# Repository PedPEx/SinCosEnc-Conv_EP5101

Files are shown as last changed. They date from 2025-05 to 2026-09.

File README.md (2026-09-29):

# EP5101 SinCos $11µA_{PP}$ and $1V_{PP}$ encoder/glass scale to TTL (RS422 compliance) converter (ARCHIVED)

This repo is no longer maintained. There is no reason to interface $11µA_{PP}$ sensors with the help of this PCB and an EtherCAT-based incremental encoder input module - like an EL5101 or an EP5101. Due to the cost of one assembled converter PCB (~30€ total), it is a competitive alternative to the original iC-Haus EVAL board of the [iC-NV](https://www.ichaus.de/product/ic-nv/) and the Heidenhain EXEs, if used with other RS422 or TTL encoder inputs.

If you are planning on using EtherCAT as your system bus, use the [documented process here on how to modify an EL5021 terminal](https://github.com/PedPEx/EL5021_multi-signal-mod) instead (which internally uses an iC-Haus IC similar to this project).

In my [bachelor's thesis](https://pedpex.github.io/Maho400E-LinuxCNC/docs/bachelors_thesis.pdf) I updated the old 0.9.6/0.9.7 version of the PCB a little, so that it better tolerates EMI conditions. As I was not very happy with the improvements in v0.9.8, it was never officially pushed. After further inspection, starting from scratch would be the better decision in order to get better EMI ratings. Additionally, the shielding of the EP5101-0011 is floating, which is also not the desired state. Since the alternative is far cheaper, a 4-layer redesign is not worthwhile, and as the new board is no longer used, this project will no longer be maintained and will therefore be archived.

PCB version v0.9.6 was fully working and successfully tested. Version v0.9.8 was never produced nor tested.
This board is provided as is - unfinished and untested. Productive use is explicitly not recommended! Further rework is required. No support is offered for it. The project will be left as is.

---

<details>
  <summary>Old README content</summary>
  
# EP5101 SinCos $11µA_{PP}$ and $1V_{PP}$ encoder/glass scale to TTL (RS422 compliance) converter (WIP!)
This interface board is designed to convert a encoder signal with $11µA_{PP}$ (peak-peak) or $1V_{PP}$ signal to TTL with a [iC-Haus iC-NV](https://www.ichaus.de/product/ic-nv/) be used with a [Beckhoff EP5101](https://www.beckhoff.com/de-de/produkte/i-o/ethercat-box/epxxxx-industriegehaeuse/ep5xxx-winkel-wegmessung/ep5101-0011.html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) for example in LinuxCNC.

Assembly concept (with old potentiometer and RJ45 jack):

Single encoder input             |  Three encoder inputs with terminal blocks
:-------------------------:|:-------------------------:
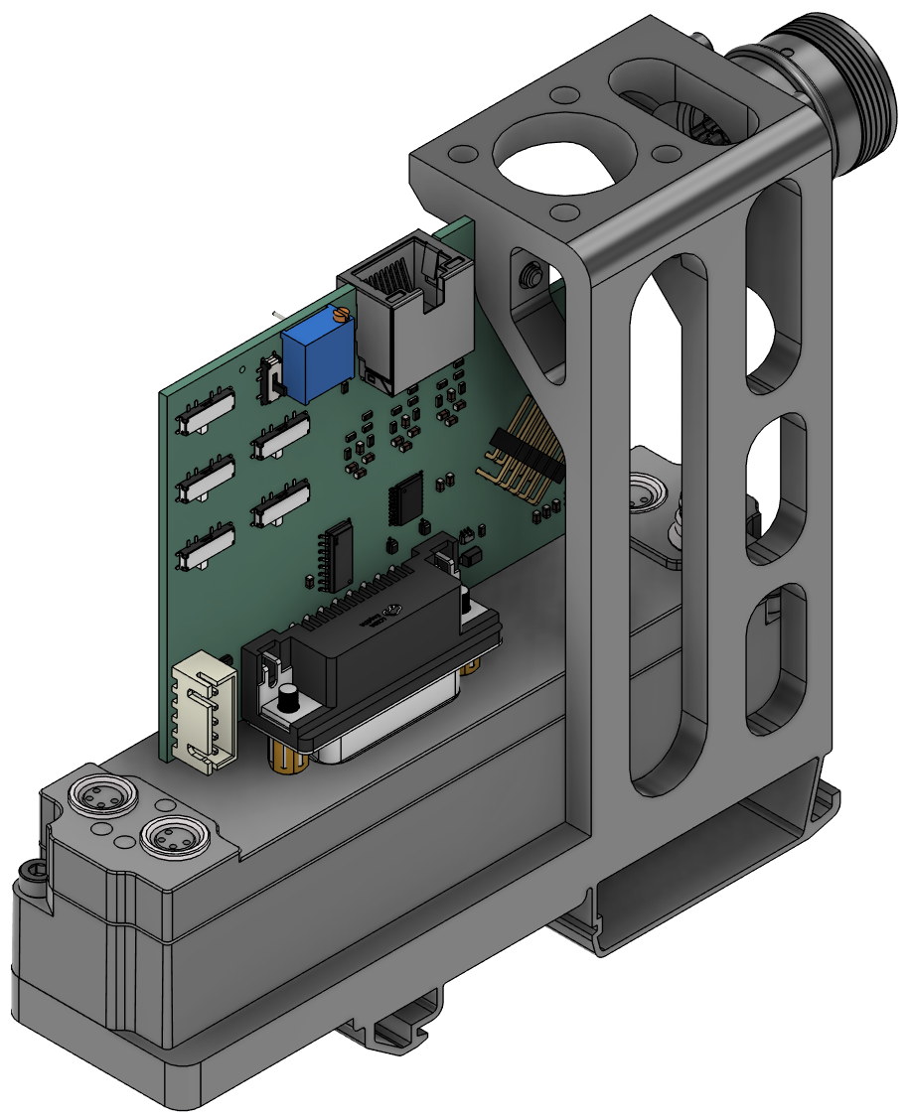
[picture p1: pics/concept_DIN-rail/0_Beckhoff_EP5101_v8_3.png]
assembly concept Concept assembly
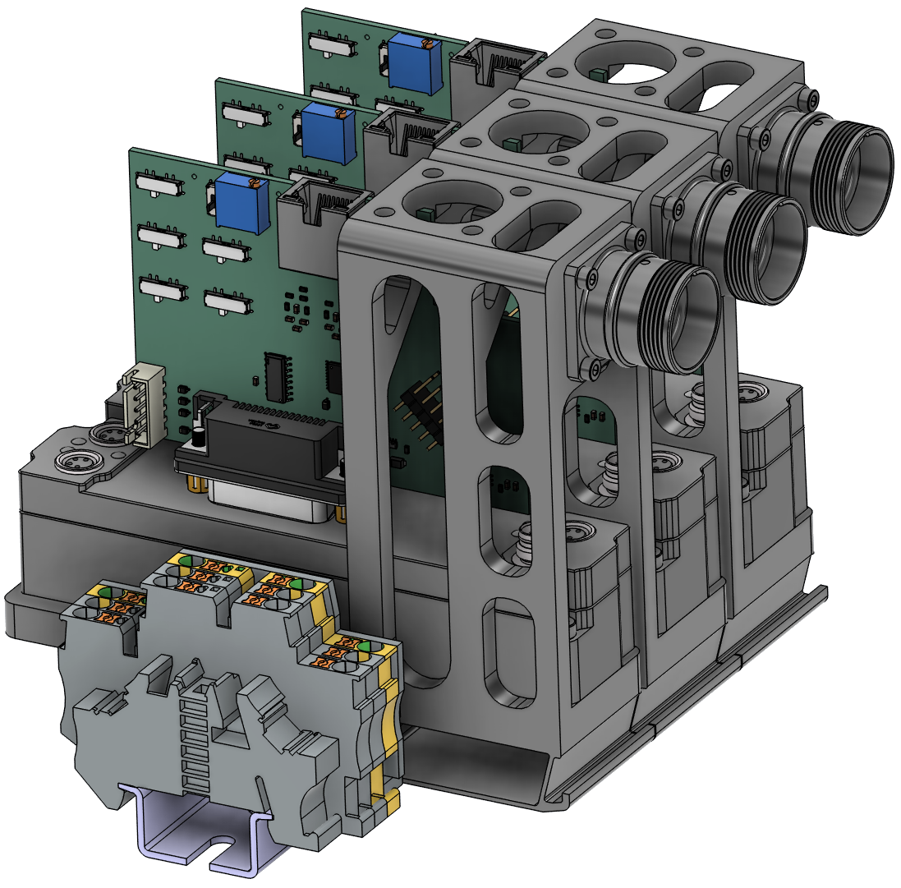
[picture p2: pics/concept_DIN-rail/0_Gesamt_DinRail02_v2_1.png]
assembly concept Concept assembly
  |  

PCB:\
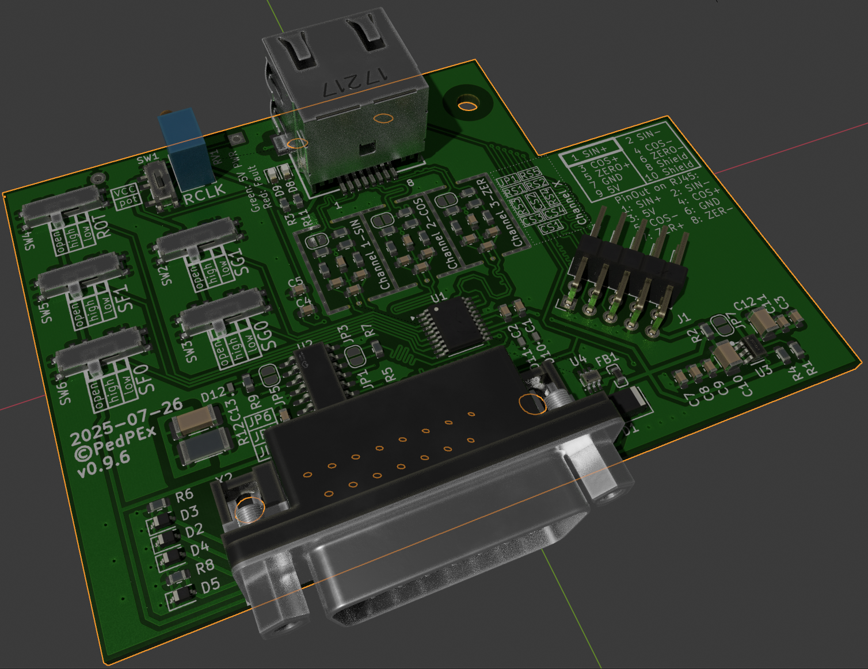
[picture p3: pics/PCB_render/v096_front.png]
PCB render v0.9.6 front

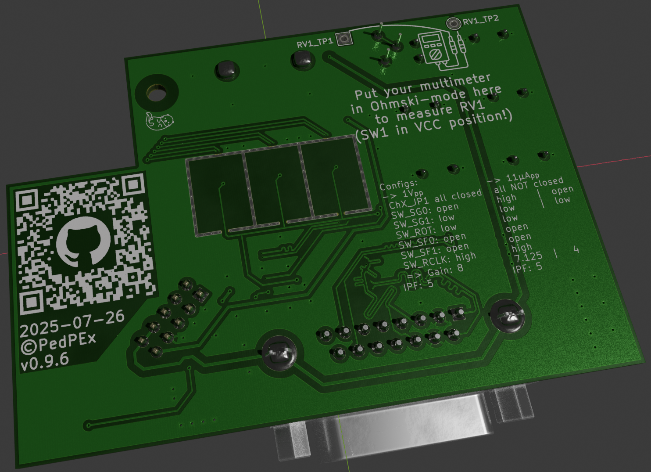
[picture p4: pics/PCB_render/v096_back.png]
PCB render v0.9.6 back


## ToDo
- ✅ finished prototype PCB (v0.9.6)
- ✅ working conversion
- ✅ tested intensively with [LS403](docs/Heidenhain-LS-403-LS-403C.pdf) and [EP5101](https://www.beckhoff.com/de-de/produkte/i-o/ethercat-box/epxxxx-industriegehaeuse/ep5xxx-winkel-wegmessung/ep5101-0011.html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)

## Powering, connectors and signals
The board needs no seperate supply voltage and is fully powered by the 5V supply of the EP5101. The green led indicates a working 5V sensor rail. Supported input signals are $11µA_{PP}$ (standard) and $1V_{PP}$. By default, the output is a differential RS422 TTL-encoder signal. In that case, component ```U2``` ([AM26LS31](https://www.ti.com/product/de-de/AM26LS31) - Differential Line Driver) is populated on the PCB. By removing ```U2``` and either manualy shorting ```JP1 - JP6``` or populating ```R5 - R10``` with $0 \Omega$ resistors (manual adjustment of BOM is required). 

Because the [Beckhoff EL5101](https://www.beckhoff.com/de-de/produkte/i-o/ethercat-klemmen/el5xxx-winkel-wegmessung/el5101.html) is way more common than the EP5101, a 3D printable holder is in the works and will also be added to the repo, as soon as it has reached a usable state. 

There could also be a master-PCB, which would be used in standalone use or with a Mesa FPGA board. This master-PCB would need a 24V to 5V regulator and three DSUB15 female connectors in order to connect to the interpolator PCBs and three connectors (RJ45 eventually?) to connect the TTL signals to the Mesa encoder inputs. A integrated DIN rail mount would make mounting easy. In case there is interest in such a board, feel free to open a issue and i will design one. 

## Mounting adaptor
There is a DIN-rail mounting adaptor avaliable, which is used to mount a M23 male connector and a EP5101 onto a 35 mm standard rail. You can find the [files to 3D print](https://than.gs/m/1345234) it yourself over on my Thangs-account.

## Config switches
Pretty much everything of the [iC-NV](https://www.ichaus.de/product/ic-nv/) is configurable through config switches and a potentiometer ($50 k\Omega$). The two most common configs are printed on the backside of the PCB

## Terminal blocks, connectors and pinouts
The shielded DSUB15 port has the following pinout:

| pin DSUB15 | usage/signal |
| :---  | :--- |
| 1 | DifSig_A+ / TTL_A |
| 2 | GND |
| 3 | DifSig_B+ / TTL_B |
| 4 | 5V VCC |
| 5 | n.c. |
| 6 | n.c. |
| 7 | DifSig_C- / TTL_GND  |
| 8 | n.c.  |
| 9 | DifSig_A- / TTL_GND  |
| 10 | GND  |
| 11 | DifSig_B- / TTL_GND  |
| 12 | 5V VCC  |
| 13 | E̅R̅R̅O̅R̅ out |
| 14 | DifSig_C+ / TTL_B  |
| 15 | n.c.  |

The shielded RJ45 port has the following pinout:

| pin RJ45 | usage/signal |
| :---  | :--- |
| 1 | In_SIN+ |
| 2 | In_SIN- |
| 3 | +5 V |
| 4 | In_COS+ |
| 5 | In_COS- |
| 6 | GND |
| 7 | In_ZERO+  |
| 8 | In_ZERO-  |

The 8 pin male-header J2 has the following pinout (standard Heidenhain pinout):

```
                        odd pins  |  even pins
╔════╦════╗             ----------|------------
║  1 ║  2 ║════════      In_SIN+  |  In_SIN-
╠════╬════╣                       |
║  3 ║  4 ║════════      In_COS+  |  In_COS-
╠════╬════╣                       |
║  5 ║  6 ║════════     In_ZERO+  |  In_ZERO-
╠════╬════╣                       |
║  7 ║  8 ║════════          GND  |  Shield
╠════╬════╣                       |
║  9 ║ 10 ║════════          +5V  |  Shield
╚════╩════╝
```

*Note:*\
DO ONLY CONNECT ONE SENSOR INPUT! NEVER USE THE PINHEADER AND RJ45 SIMULTANEOUSLY!

## Analog Frontend / Signal Conditioning Stage
After reaching out to iC-Haus' support for some details about the needed analog frontend for $11 µA_{PP}$ sensors, i got some details on how to implement it. A really nice solution which works with $1 V_{PP}$ as well as $11 µA_{PP}$ signals was documented in the [iC-NQC datasheet (page 28)](docs/iC-NQC_datasheet_E2en.pdf). This exact signal conditioning stage was implemented for all three stages. By shorting each ```CHx_JP1``` you can connect the $120 \Omega$ termination resistor to the input side of the input stage and by that set the device to its $1 V_{PP}$ operating mode.

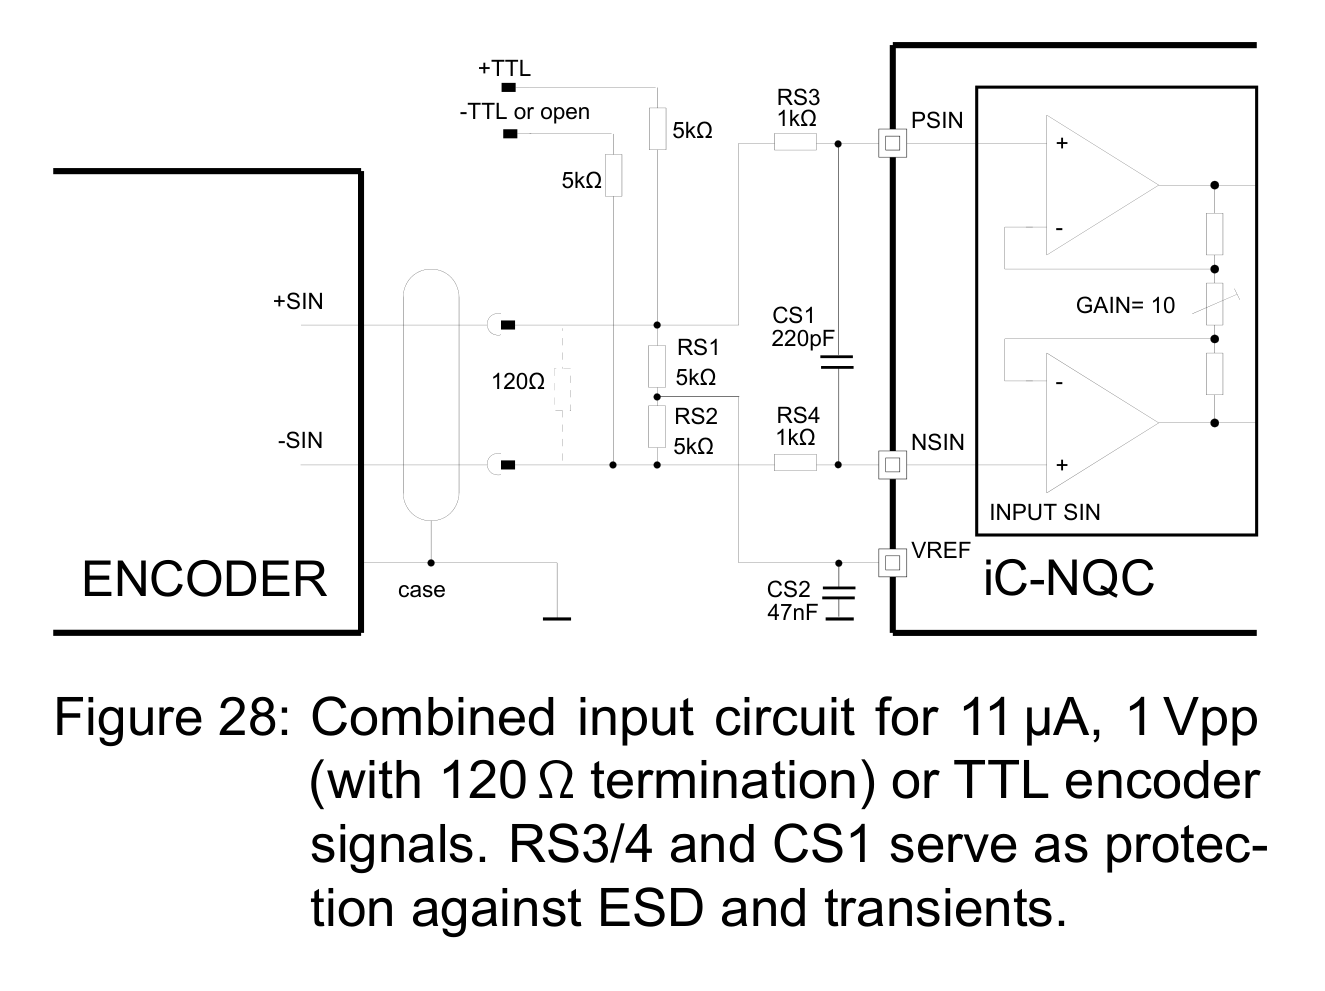
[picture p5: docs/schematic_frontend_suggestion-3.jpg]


## Usage/Software
This interface board is meant to be used in combination with the [Beckhoff EP5101 module](hhttps://www.beckhoff.com/de-de/produkte/i-o/ethercat-box/epxxxx-industriegehaeuse/ep5xxx-winkel-wegmessung/ep5101-0011.html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). The EP5101 is then used by the [LinuxCNC software](https://linuxcnc.org/) to read e.g. Heidenhain LS403 glass scales on a Maho MH400E.

A adaptor/mounting kit is in the works, that this project can also be used with [Beckhoffs EL5101](https://www.beckhoff.com/de-de/produkte/i-o/ethercat-klemmen/el5xxx-winkel-wegmessung/el5101.html) encoder inputs.

Also keep in mind that you need a sufficiently sized counter. For most retrofits a 16 bit wide counter will not cut it. 
Quick example:
```math 
n_{min} = \log_2 \left(\frac{range\_of\_motion}{axis\_resolution}\right) = \log_2 \left(\frac{400 mm}{1 \mu m}\right) = 18.61 bit \approx \textbf{19 bit > 16 bit}
```
In addition to the resolution you you also need to check the cutoff frequency (maximum input frequency) of the encoder input. The ```EP5101-0011``` for example is limited to $1.0 MHz$ (that's really high, especally in fourfold evaluation mode). For a resolution of $1 µm$ the maximum axis speed is:
```math
v_{max\_EC-Input} = \frac{resolution\_of\_sensor}{interpolation\_factor \cdot quadratur\_encoder\_input} \cdot cutoff\_frequency = {overall\_resolution \cdot cutoff\_frequency} = \frac{20µm}{5 \cdot 4} \cdot 1.0 MHz = 1µm \cdot 1.0 MHz = 1.0 \frac{m}{s}
```
The same calculation needs to be done with the input side of the IC ```iC-NV```. The cutoff frequency depends on the used gain. For a $gain = 4$ the manual states a $fin_{MAX}=200 kHz$ (for RCLK = VCC).
```math
v_{max\_IC-Input} = resolution\_of\_sensor \cdot cutoff\_frequency_{IC} = 20µm \cdot 200 kHz = 4.0 \frac{m}{s}
```
The lower value of the two calculated velocities, $v_{max\_{EC-Input}} = 1.0 \frac{m}{s}$ and $v_{max\_IC-Input} = 4.0 \frac{m}{s}$, is $1.0 \frac{m}{s}$. This represents the maximum permissible speed for the corresponding axis and must not be exceeded!

## Documentation
All docs can be found in the [docs folder](docs/).

## Online Preview / BOM
[Detailed schematics preview](https://kicanvas.org/?github=https%3A%2F%2Fgithub.com%2FPedPEx%2FSinCosEnc-Conv_EP5101) (KiCanvas)

[Online BOM](https://htmlpreview.github.io/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)

[PDF schematics (v0.9.6)](https://github.com/PedPEx/SinCosEnc-Conv_EP5101/blob/master/SinCosEnc-Converter_EP5101-0011_schematic_v0.9.6.pdf)

## *Note*
The pictures were rendered with the help of Blender and the [pcb2blender](https://github.com/30350n/pcb2blender) plugin and the HTML BOM was created with [InteractiveHtmlBom](https://github.com/openscopeproject/InteractiveHtmlBom).

</details>

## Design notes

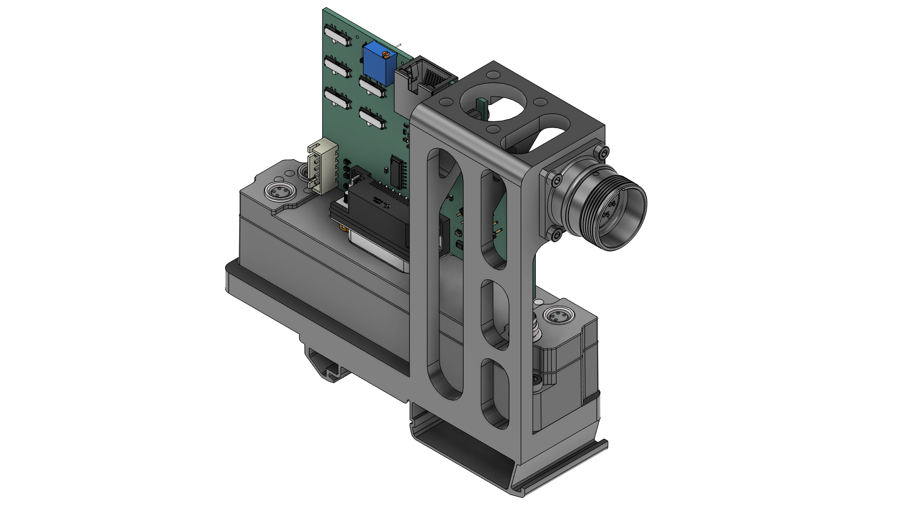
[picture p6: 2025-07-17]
pics/concept_DIN-rail/0_Beckhoff_EP5101_v8_1.png

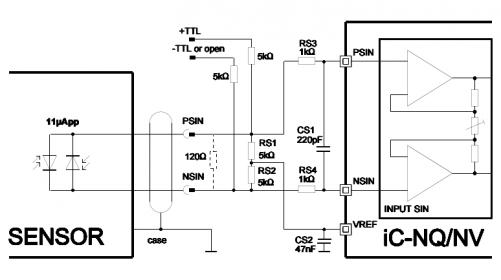
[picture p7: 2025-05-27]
docs/schematic_frontend_suggestion-1.jpg

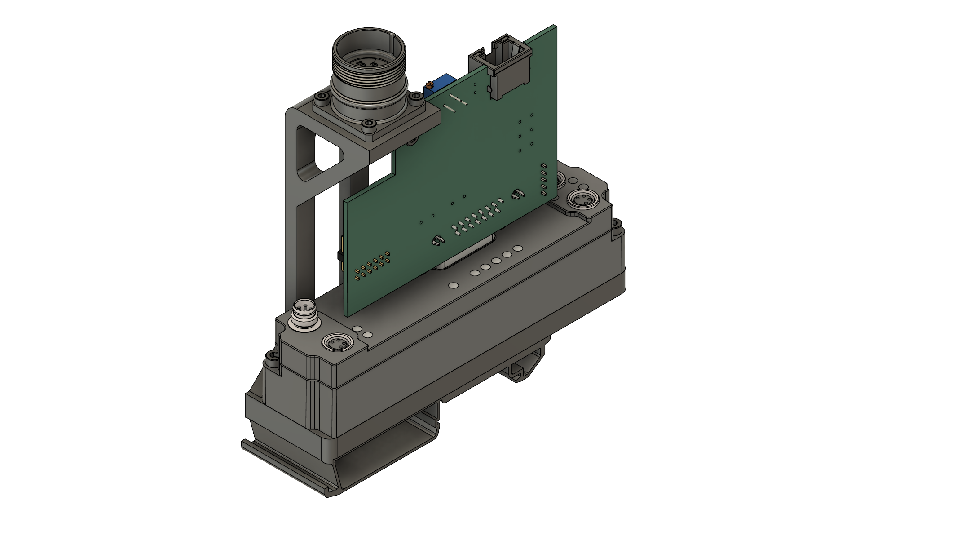
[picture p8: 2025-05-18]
pics/concept_DIN-rail/0_Beckhoff_EP5101_v4_1.png

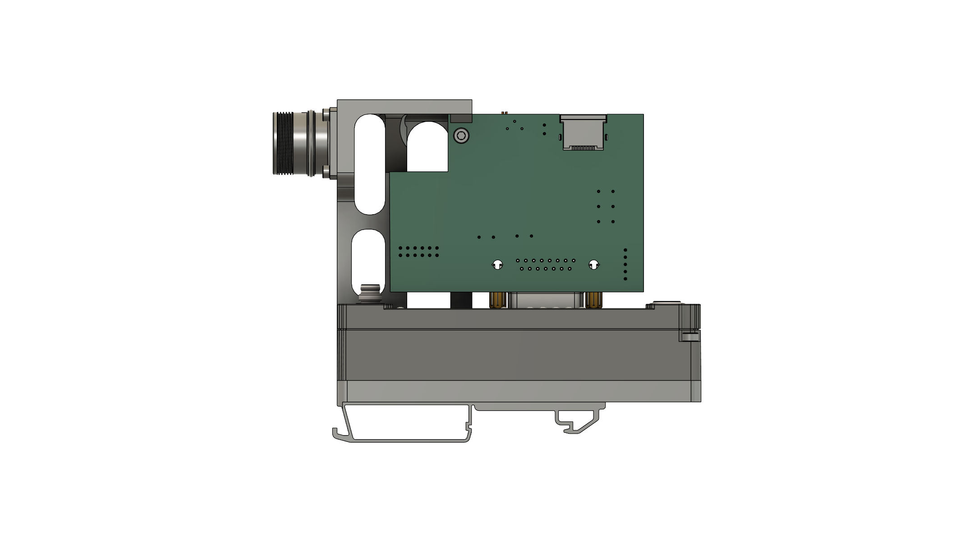
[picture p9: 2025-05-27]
pics/concept_DIN-rail/0_Beckhoff_EP5101_v5_4.png

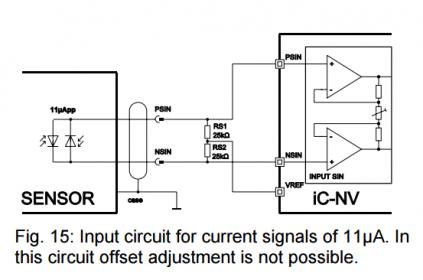
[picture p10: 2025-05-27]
docs/schematic_frontend_suggestion-2.jpg

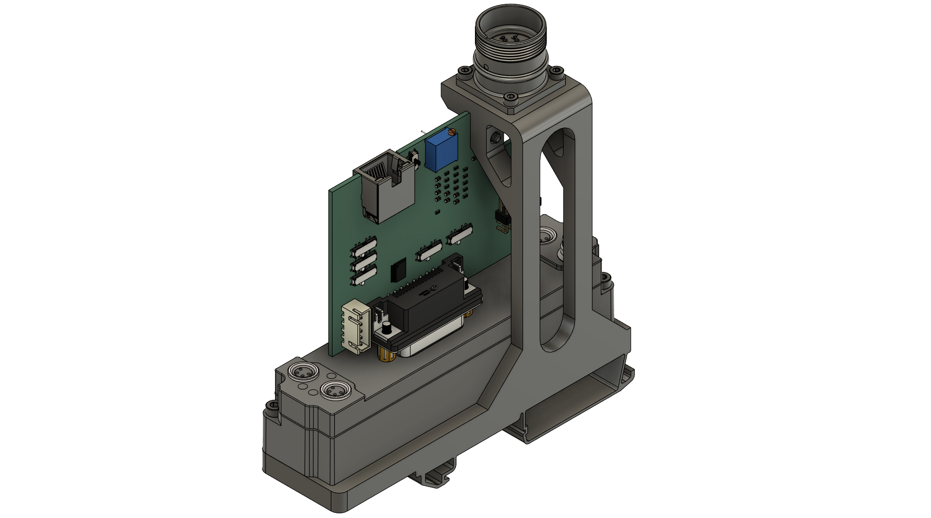
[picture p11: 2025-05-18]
pics/concept_DIN-rail/0_Beckhoff_EP5101_v4_6.png

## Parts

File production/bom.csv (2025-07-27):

Designator | Footprint | Quantity | Value | LCSC Part #
C1, C2, C4, C5, C6, C7 | 0603 | 6 | 100n
C10, C12 | 1206 | 2 | 47u | C94034
C11 | 0603 | 1 | 0.1u
C13 | 1808 | 1 | 4n7 | C161101
C3 | 0603 | 1 | 4u7 | C1705
C8 | 0603 | 1 | 1u
C9 | 0603 | 1 | 10u
Ch1_CS1, Ch2_CS1, Ch3_CS1 | 0603 | 3 | 220p
Ch1_CS2, Ch2_CS2, Ch3_CS2 | 0603 | 3 | 47n
Ch1_CS3, Ch1_CS4, Ch2_CS3, Ch2_CS4, Ch3_CS3, Ch3_CS4 | 0603 | 6 | 470p
Ch1_RS1, Ch1_RS2, Ch2_RS1, Ch2_RS2, Ch3_RS1, Ch3_RS2 | 0603 | 6 | 50k | C861451
Ch1_RS3, Ch1_RS4, Ch2_RS3, Ch2_RS4, Ch3_RS3, Ch3_RS4 | 0603 | 6 | 1k
Ch1_RS5, Ch2_RS5, Ch3_RS5 | 0603 | 3 | 120
D1 | D_SMA | 1 | SMAJ5.0CA | C83324
D10, D11, D12 | Texas_DPY0002A_0.6x1mm_P0.65mm | 3 | ESD401DPYR | C1974752
D2, D3, D4, D5, D6, D7 | D_SOD-323 | 6 | SD15 | C207245
D8 | 0603 | 1 | LED RED | C2986060
D9 | 0603 | 1 | LED GREEN | C2986059
FB1 | L0603 | 1 | 100R@100MHz | C107332
J1 | PinHeader_2x05_P2.54mm_Horizontal | 1 | Conn_02x05_Top_Bottom | C492433
R1 | 0603 | 1 | 215k | C22954
R10, R2, R5, R6, R7, R8, R9 | 0603 | 7 | 0
R11, R3 | 0603 | 2 | 470
R12 | 2010 | 1 | 1M | C2779367
R4 | 0603 | 1 | 10k
RJ1 | RJ45-SMD_6339160-1 | 1 | 6339160-1 | C125076
RV1 | Potentiometer_Bourns_3266X_Horizontal | 1 | 50k | C780222
RV1_TP1 | TestPoint_THTPad_2.0x2.0mm_Drill1.0mm | 1 | TestPoint_RV1
RV1_TP2 | TestPoint_THTPad_D2.0mm_Drill1.0mm | 1 | TestPoint_RV1
SW1 | SW-SMD_XKB_SS-3292S-L2-W | 1 | SW_RCLK | C2884756
SW2 | SW-SMD_MSK13C02-BB | 1 | SW_SG1 | C5149819
SW3 | SW-SMD_MSK13C02-BB | 1 | SW_SG0 | C5149819
SW4 | SW-SMD_MSK13C02-BB | 1 | SW_ROT | C5149819
SW5 | SW-SMD_MSK13C02-BB | 1 | SW_SF1 | C5149819
SW6 | SW-SMD_MSK13C02-BB | 1 | SW_SF0 | C5149819
U1 | TSSOP-20_4.4x6.5mm_P0.65mm | 1 | iC-NV
U2 | SOIC-16_L9.9-W3.9-P1.27-LS6.0-BL | 1 | AM26LS31CDR | C6179
U3 | SOT-23-6_L2.9-W1.6-P0.95-LS2.8-BL | 1 | AP22652AW6-7 | C5329413
U4 | SC-70-6_L2.0-W1.3-P0.65-LS2.1-BL | 1 | LM66100DCKR | C2869734
X2 | DSUB-TH_D-SUB-DR-15PCG-AB | 1 | D-SUB-DR-15PCG-AB | C19077347

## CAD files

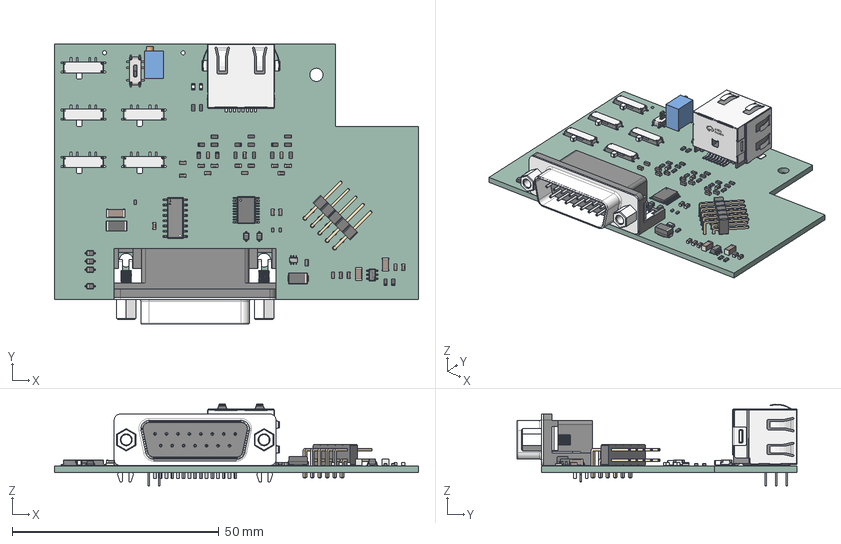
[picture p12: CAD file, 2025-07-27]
3D/SinCosEnc-Converter_EP5101-0011_v096.step
88.0 x 67.8 x 19.7 mm
R_2010_5025Metric
C_0603_1608Metric x 22
D_SMA
R_0603_1608Metric x 19
X1SON-2_L1.0-W0.6-H0.4-P0.65 x 3
SOT-23-6_L2.9-W1.6-H1.5-LS2.8-P0.95
SC-70-6_L2.0-W1.3-P0.65-LS2.1-BL
SOIC-16_L9.9-W3.9-H1.8-LS6.0-P1.27
SW-SMD_MSK13C02-BB x 5
C_1206_3216Metric x 2
Potentiometer_Bourns_3266X_Horizontal
LED_0603_1608Metric x 2
D_SOD_323 x 6
TSSOP_20_44x65mm_P065mm
SW-SMD_SS-3292S-L2-B
C_1808_4520Metric
PinHeader_2x05_P254mm_Horizontal
DSUB-TH_D-SUB-DR-15PCG-AB
L0603_L1.6-W0.8-H0.5_BEAD
RJ45-SMD_6339160-1
SinCosEnc-Converter_EP5101-0011_PCB

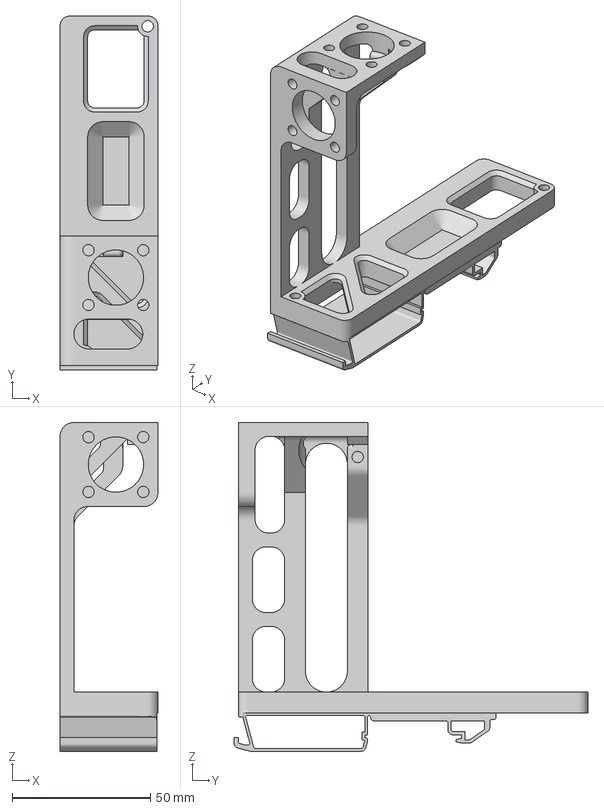
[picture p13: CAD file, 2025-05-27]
3D/EP5101-0011_DinRail_CON-downside_v4.3mf
35.4 x 128.0 x 119.0 mm

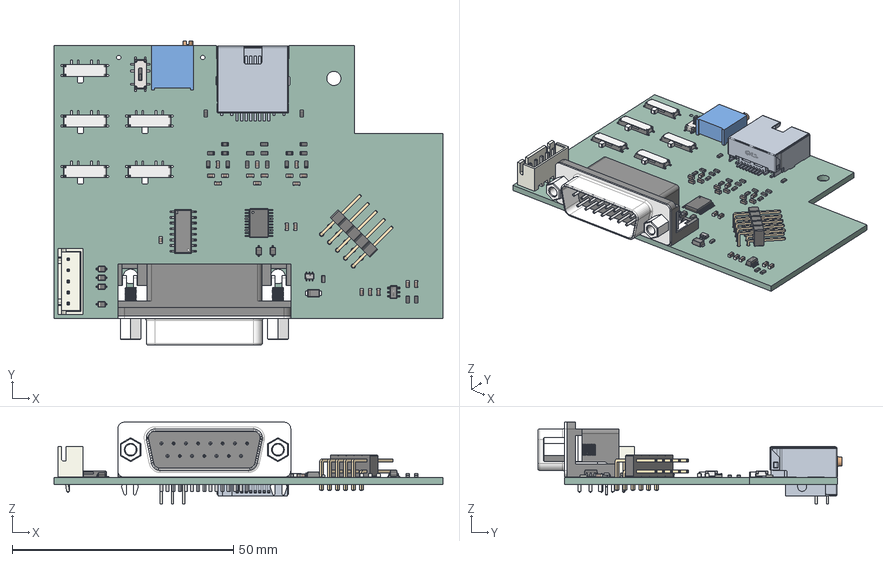
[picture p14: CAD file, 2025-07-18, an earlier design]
3D/SinCosEnc-Converter_EP5101-0011_v094.step
88.0 x 68.8 x 18.5 mm
C_0603_1608Metric x 20
R_0603_1608Metric x 19
SOT-23-6_L2.9-W1.6-H1.5-LS2.8-P0.95
SC-70-6_L2.0-W1.3-P0.65-LS2.1-BL
SOIC-16_L9.9-W3.9-H1.8-LS6.0-P1.27
SW-SMD_MSK13C02-BB x 5
Potentiometer_Bourns_3296P_Horizontal
D_SOD_323 x 6
TSSOP_20_44x65mm_P065mm
SW-SMD_SS-3292S-L2-B
JST_B5B_XH_A
RJ45-TH_RC01812_ASM
SOD-123FL_L2.8-W1.8-LS3.7-RD-1
PinHeader_2x05_P254mm_Horizontal
DSUB-TH_D-SUB-DR-15PCG-AB
L0603_L1.6-W0.8-H0.5_BEAD
_autosave-SinCosEnc-Converter_EP5101-0011_PCB

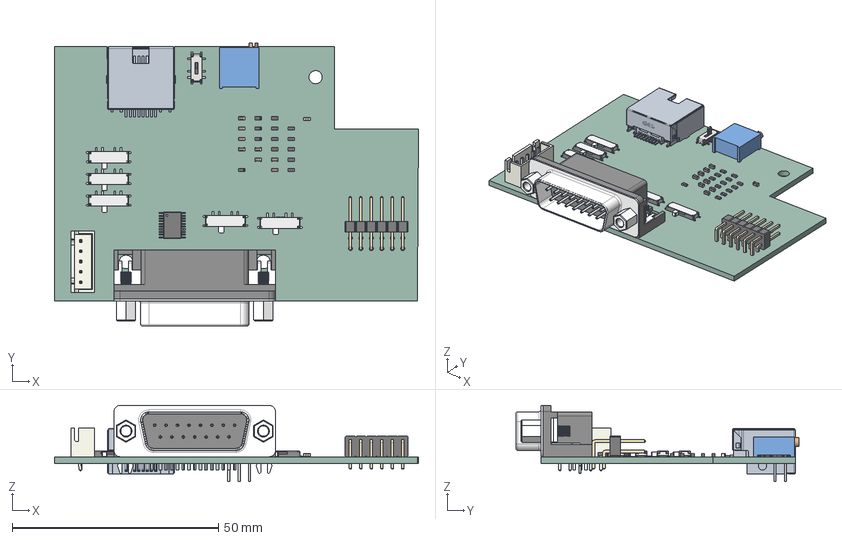
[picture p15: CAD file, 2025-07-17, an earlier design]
3D/SinCosEnc-Converter_EP5101-0011.step
88.3 x 68.6 x 18.5 mm
R_0603_1608Metric x 13
C_0603_1608Metric x 9
SW-SMD_MSK13C02-BB x 5
Potentiometer_Bourns_3296P_Horizontal
TSSOP_20_44x65mm_P065mm
SW-SMD_SS-3292S-L2-B
PinHeader_2x06_P254mm_Horizontal
JST_B5B_XH_A
RJ45-TH_RC01812_ASM
DSUB-TH_D-SUB-DR-15PCG-AB
SinCosEnc-Converter_EP5101-0011_PCB

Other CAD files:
3D/SinCosEnc-Converter_EP5101-0011_v093.step
3D/EP5101-0011_DinRail_CON-downside_v3.3mf

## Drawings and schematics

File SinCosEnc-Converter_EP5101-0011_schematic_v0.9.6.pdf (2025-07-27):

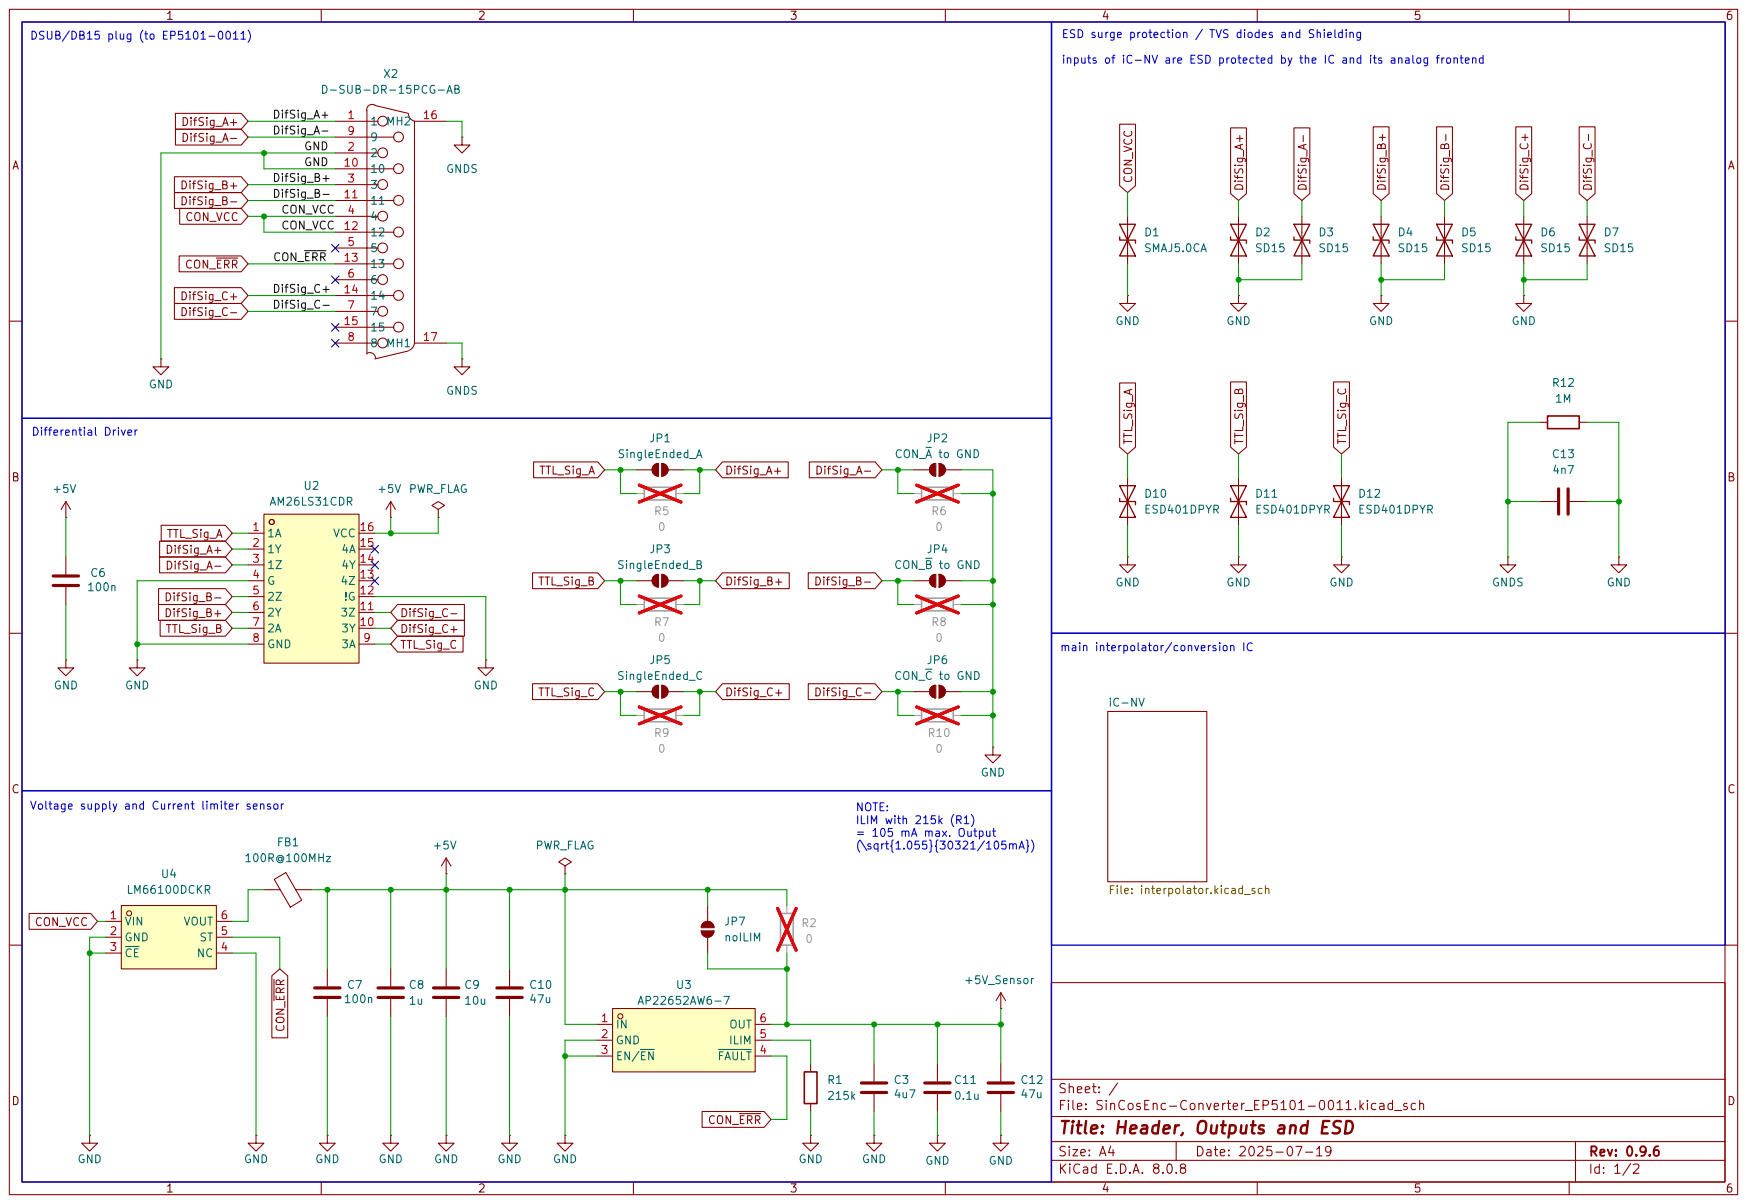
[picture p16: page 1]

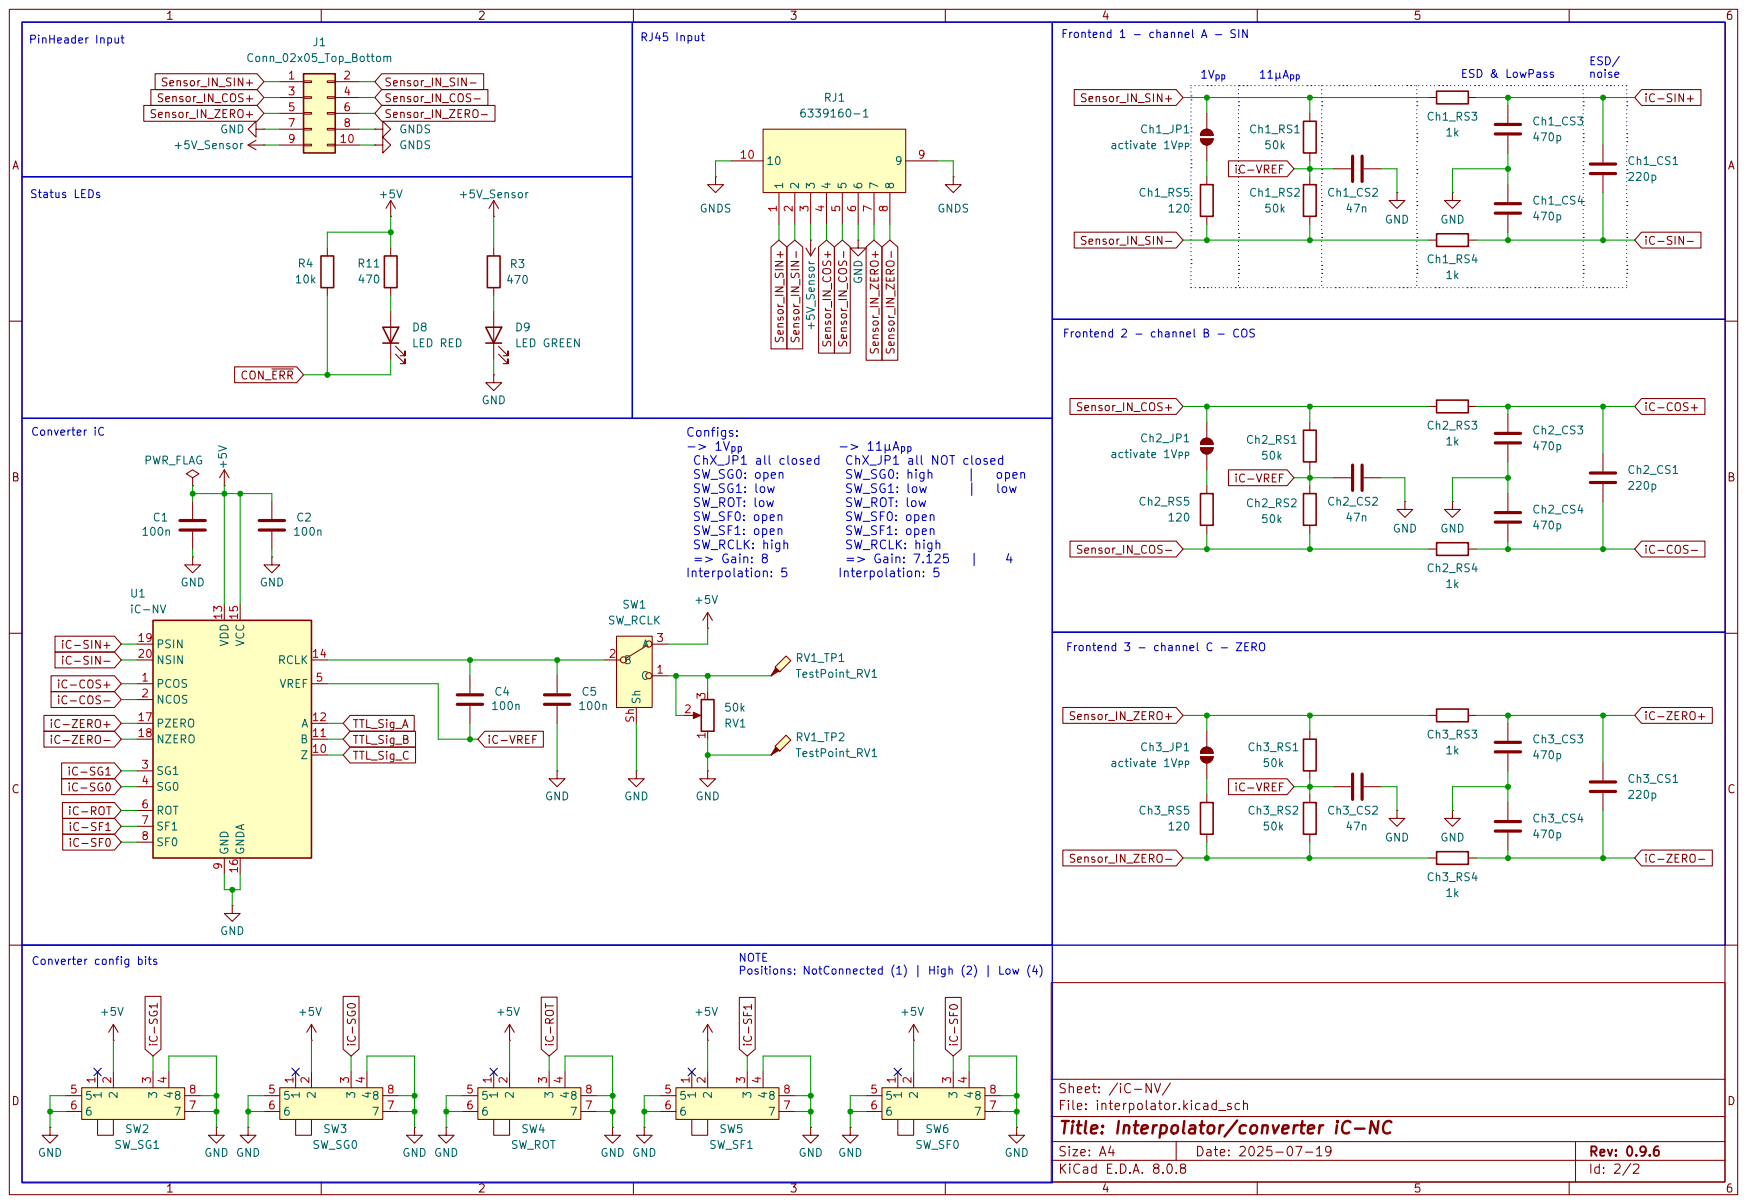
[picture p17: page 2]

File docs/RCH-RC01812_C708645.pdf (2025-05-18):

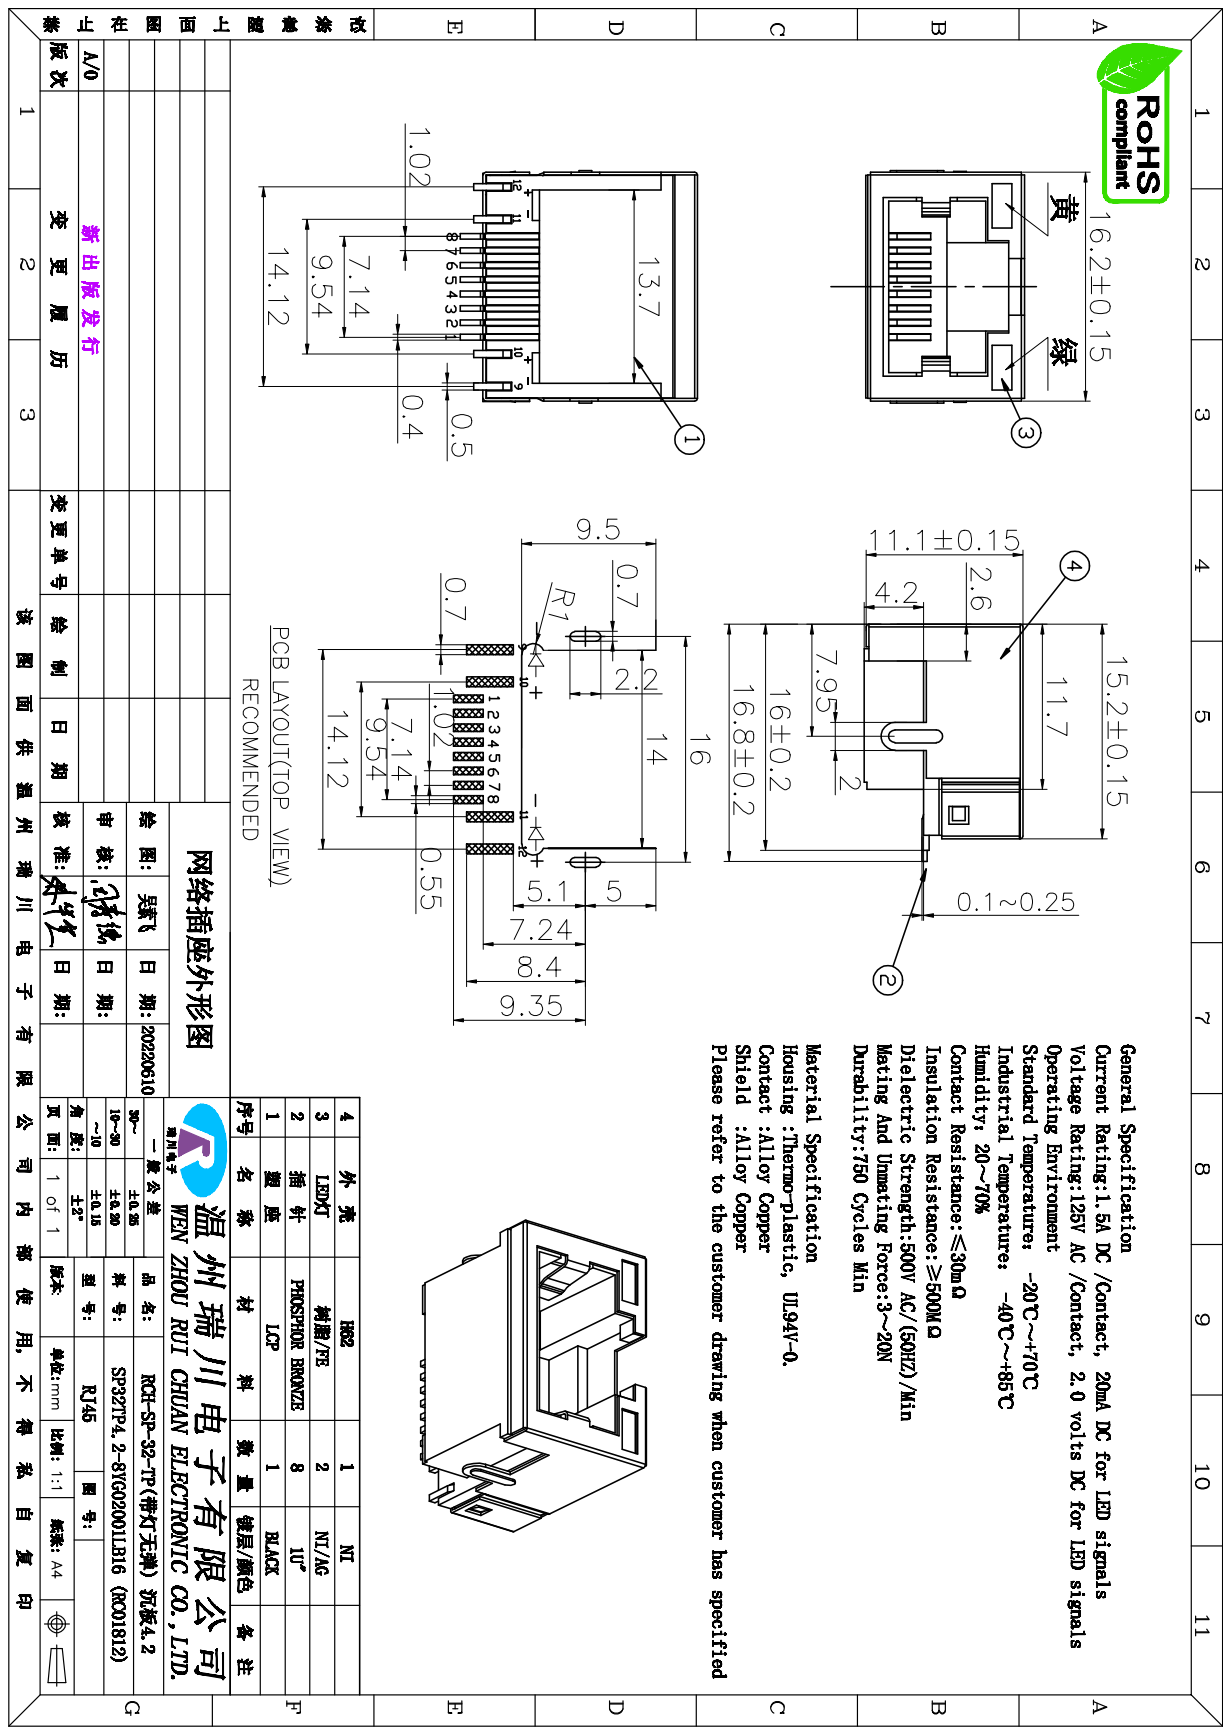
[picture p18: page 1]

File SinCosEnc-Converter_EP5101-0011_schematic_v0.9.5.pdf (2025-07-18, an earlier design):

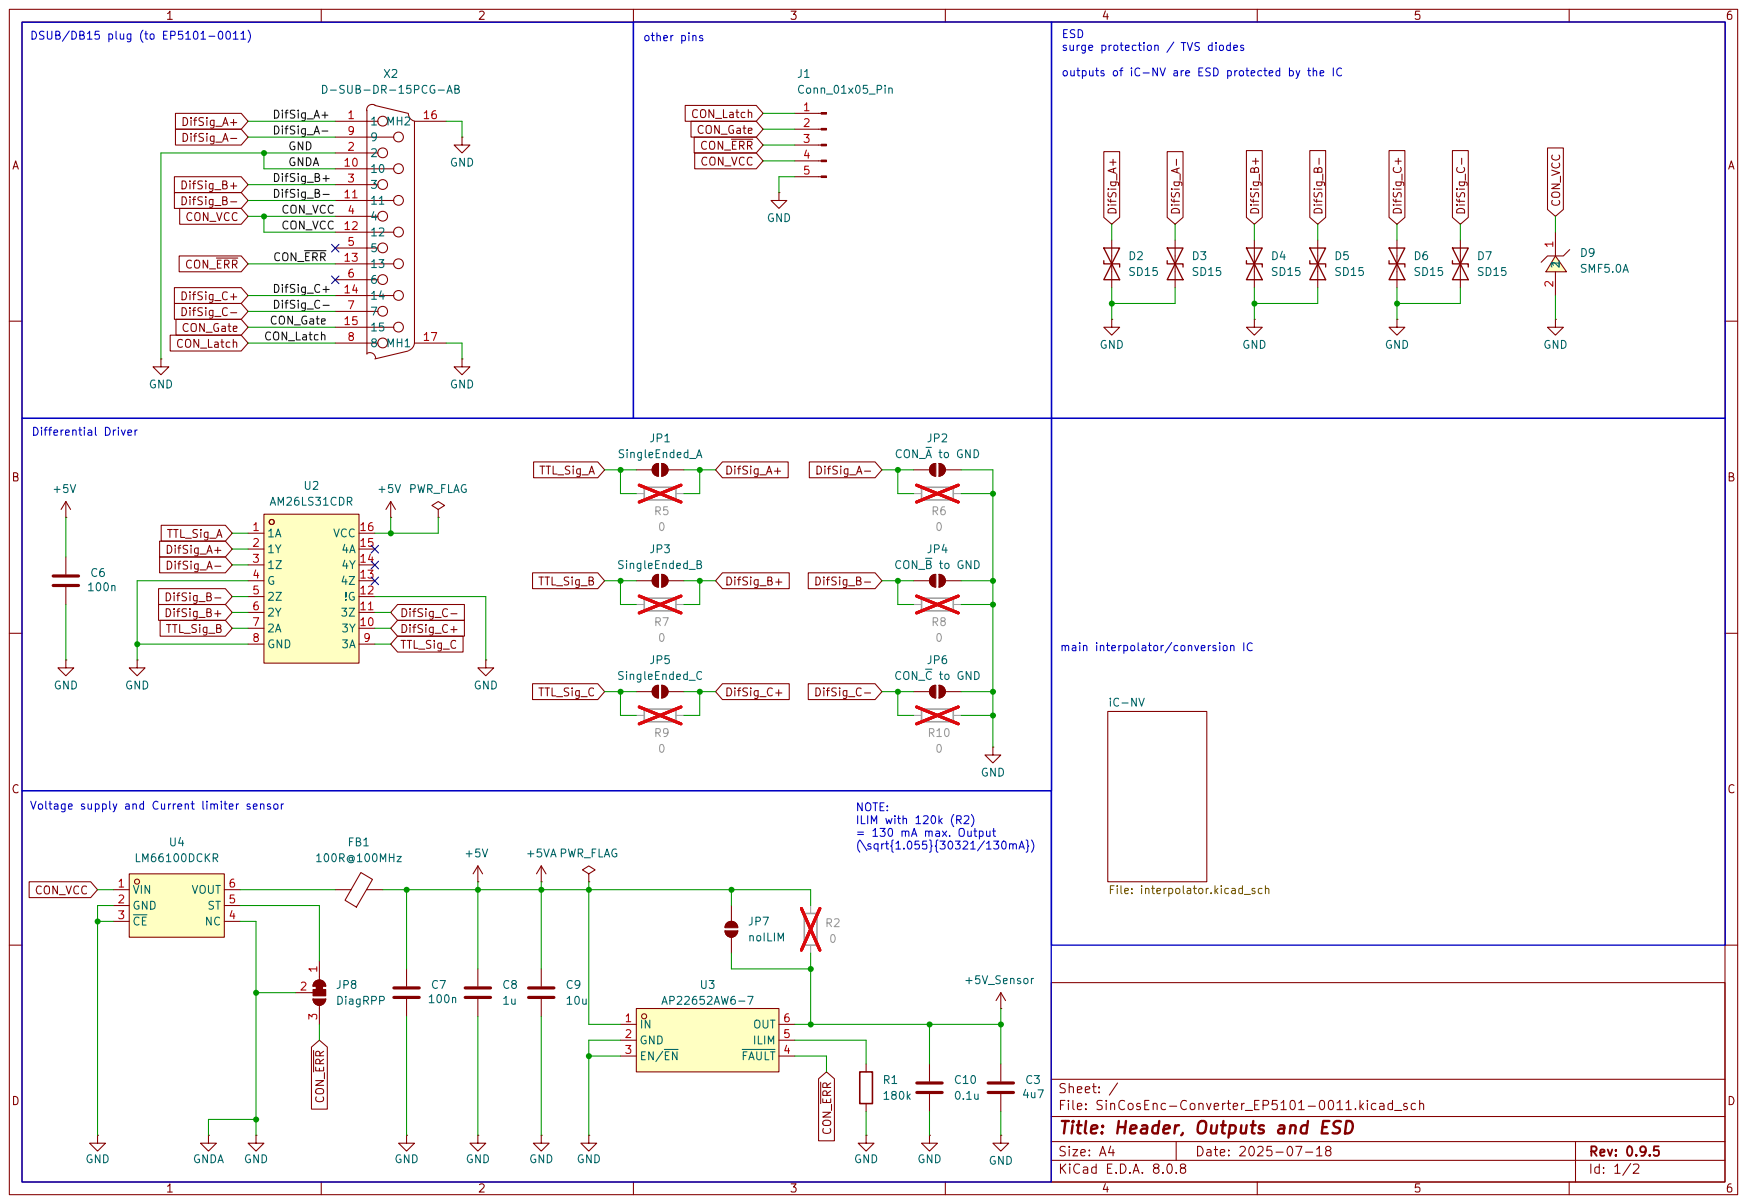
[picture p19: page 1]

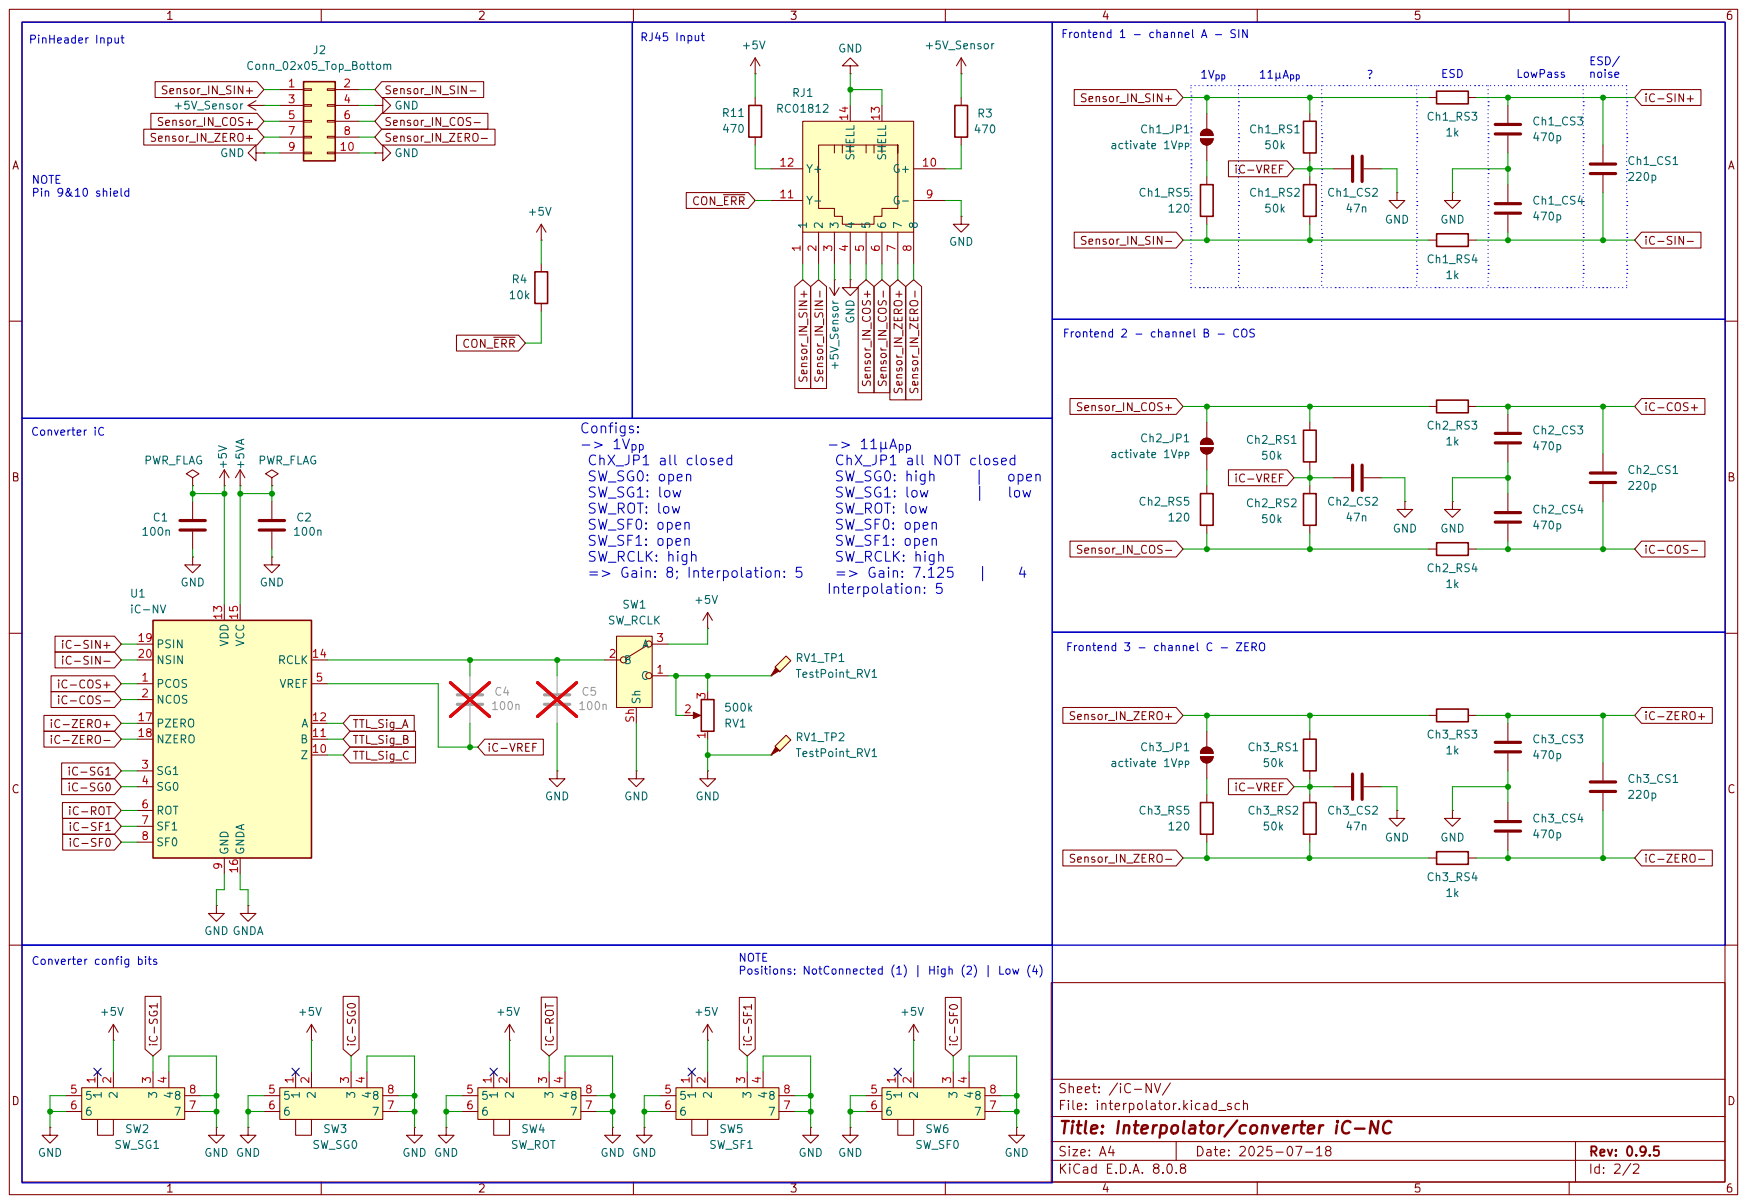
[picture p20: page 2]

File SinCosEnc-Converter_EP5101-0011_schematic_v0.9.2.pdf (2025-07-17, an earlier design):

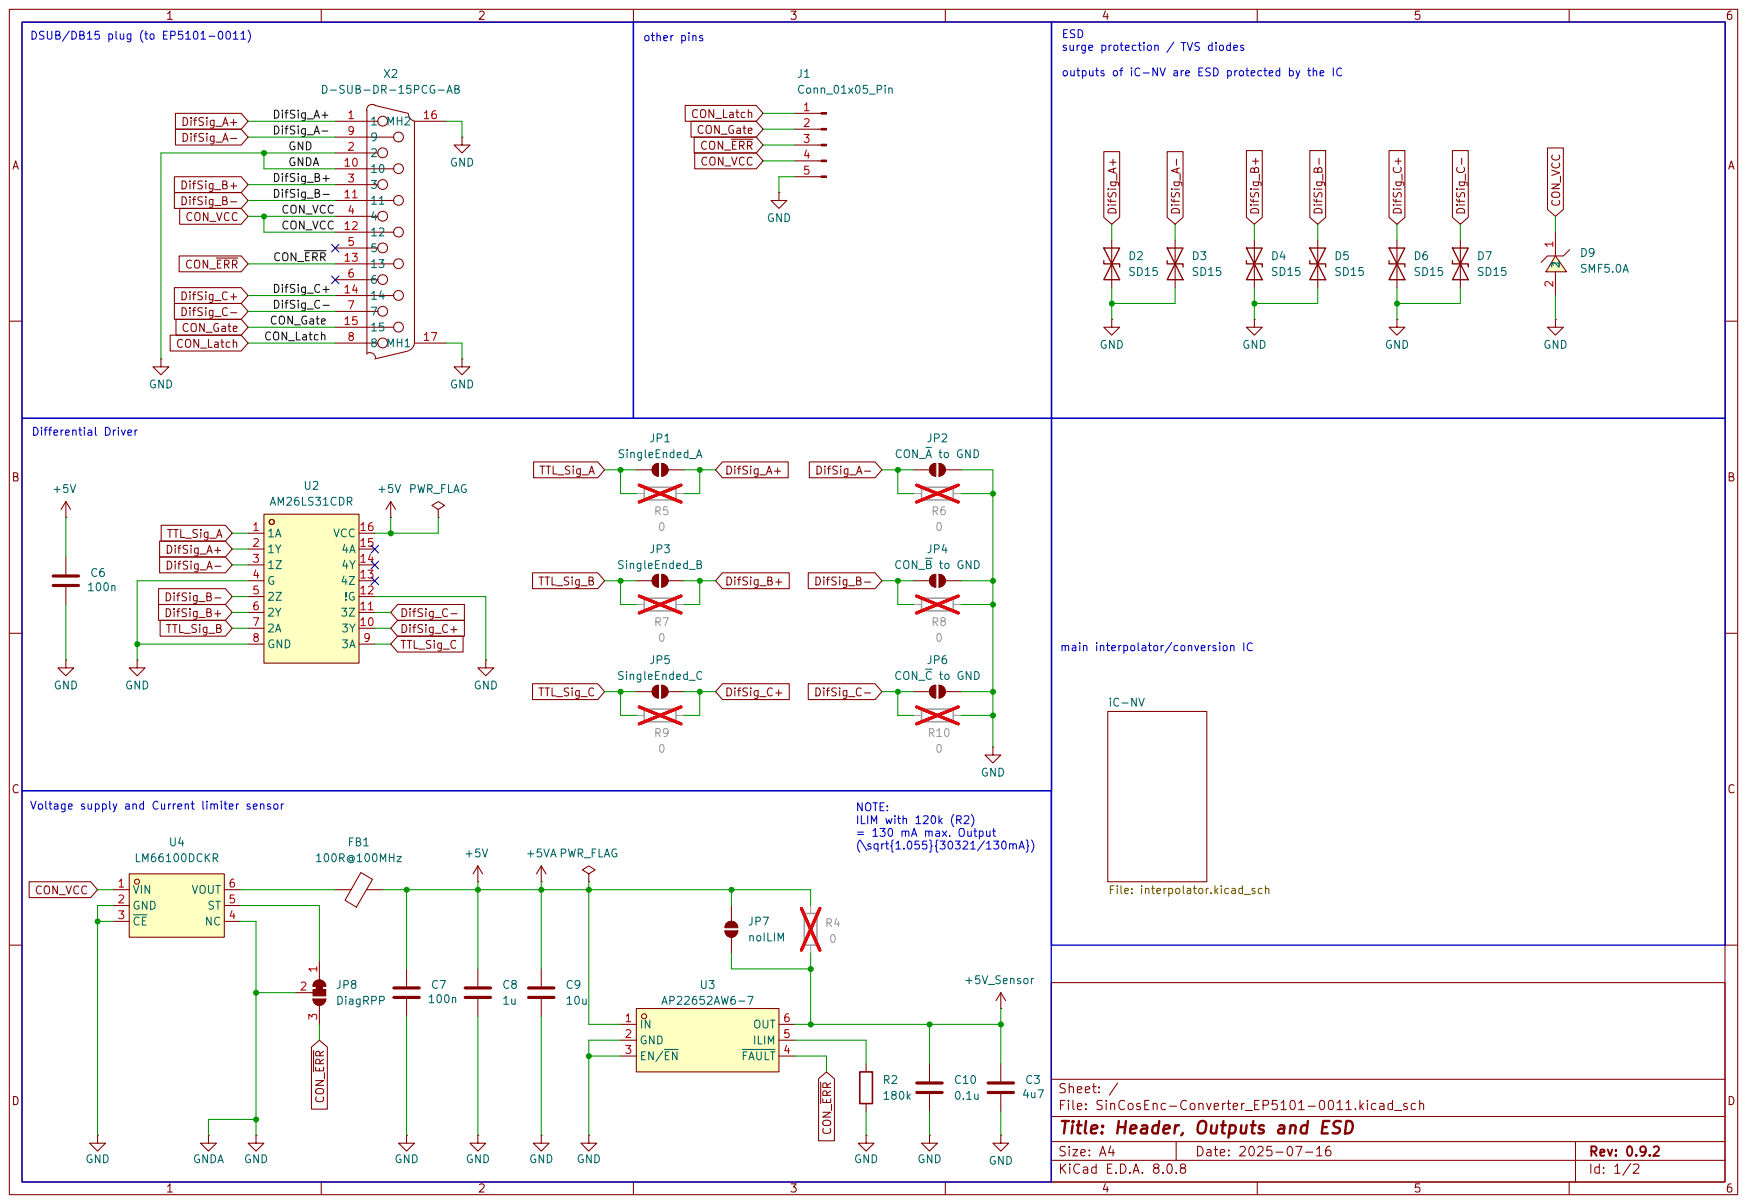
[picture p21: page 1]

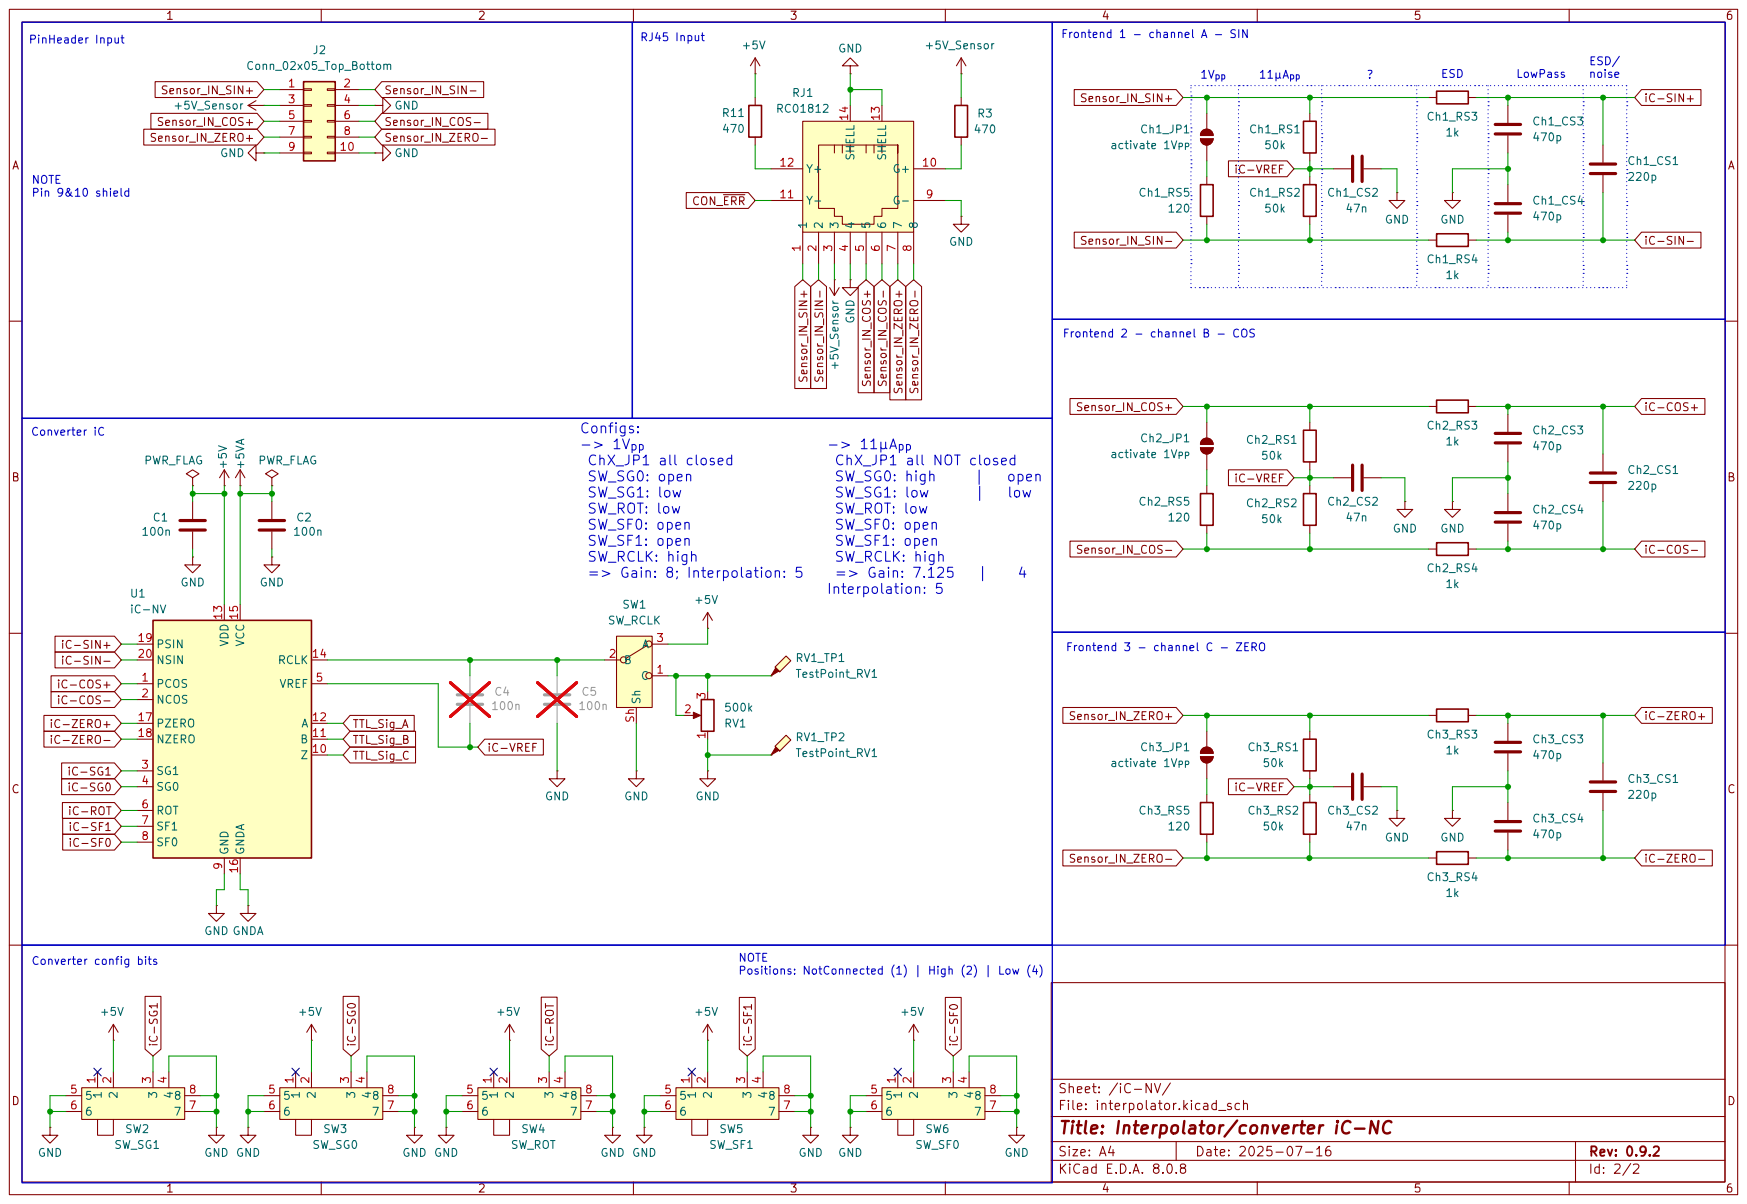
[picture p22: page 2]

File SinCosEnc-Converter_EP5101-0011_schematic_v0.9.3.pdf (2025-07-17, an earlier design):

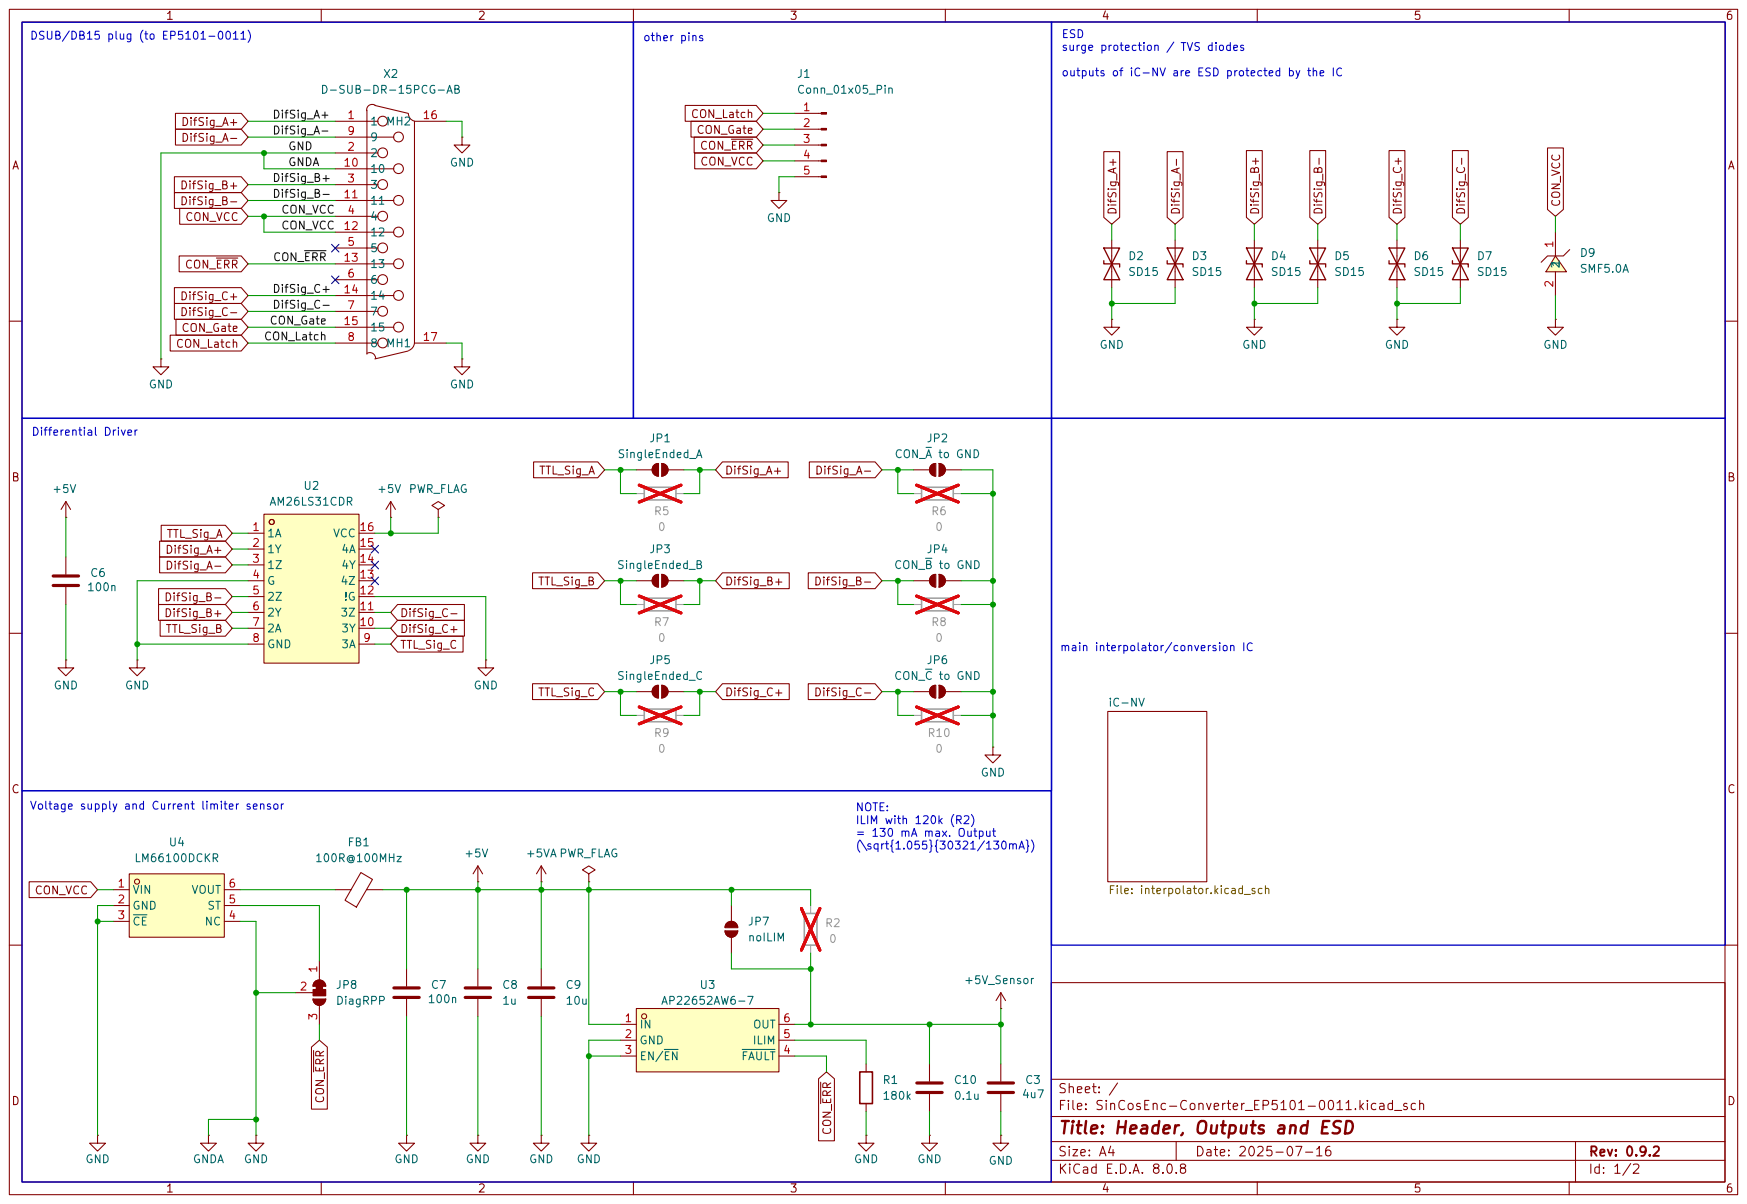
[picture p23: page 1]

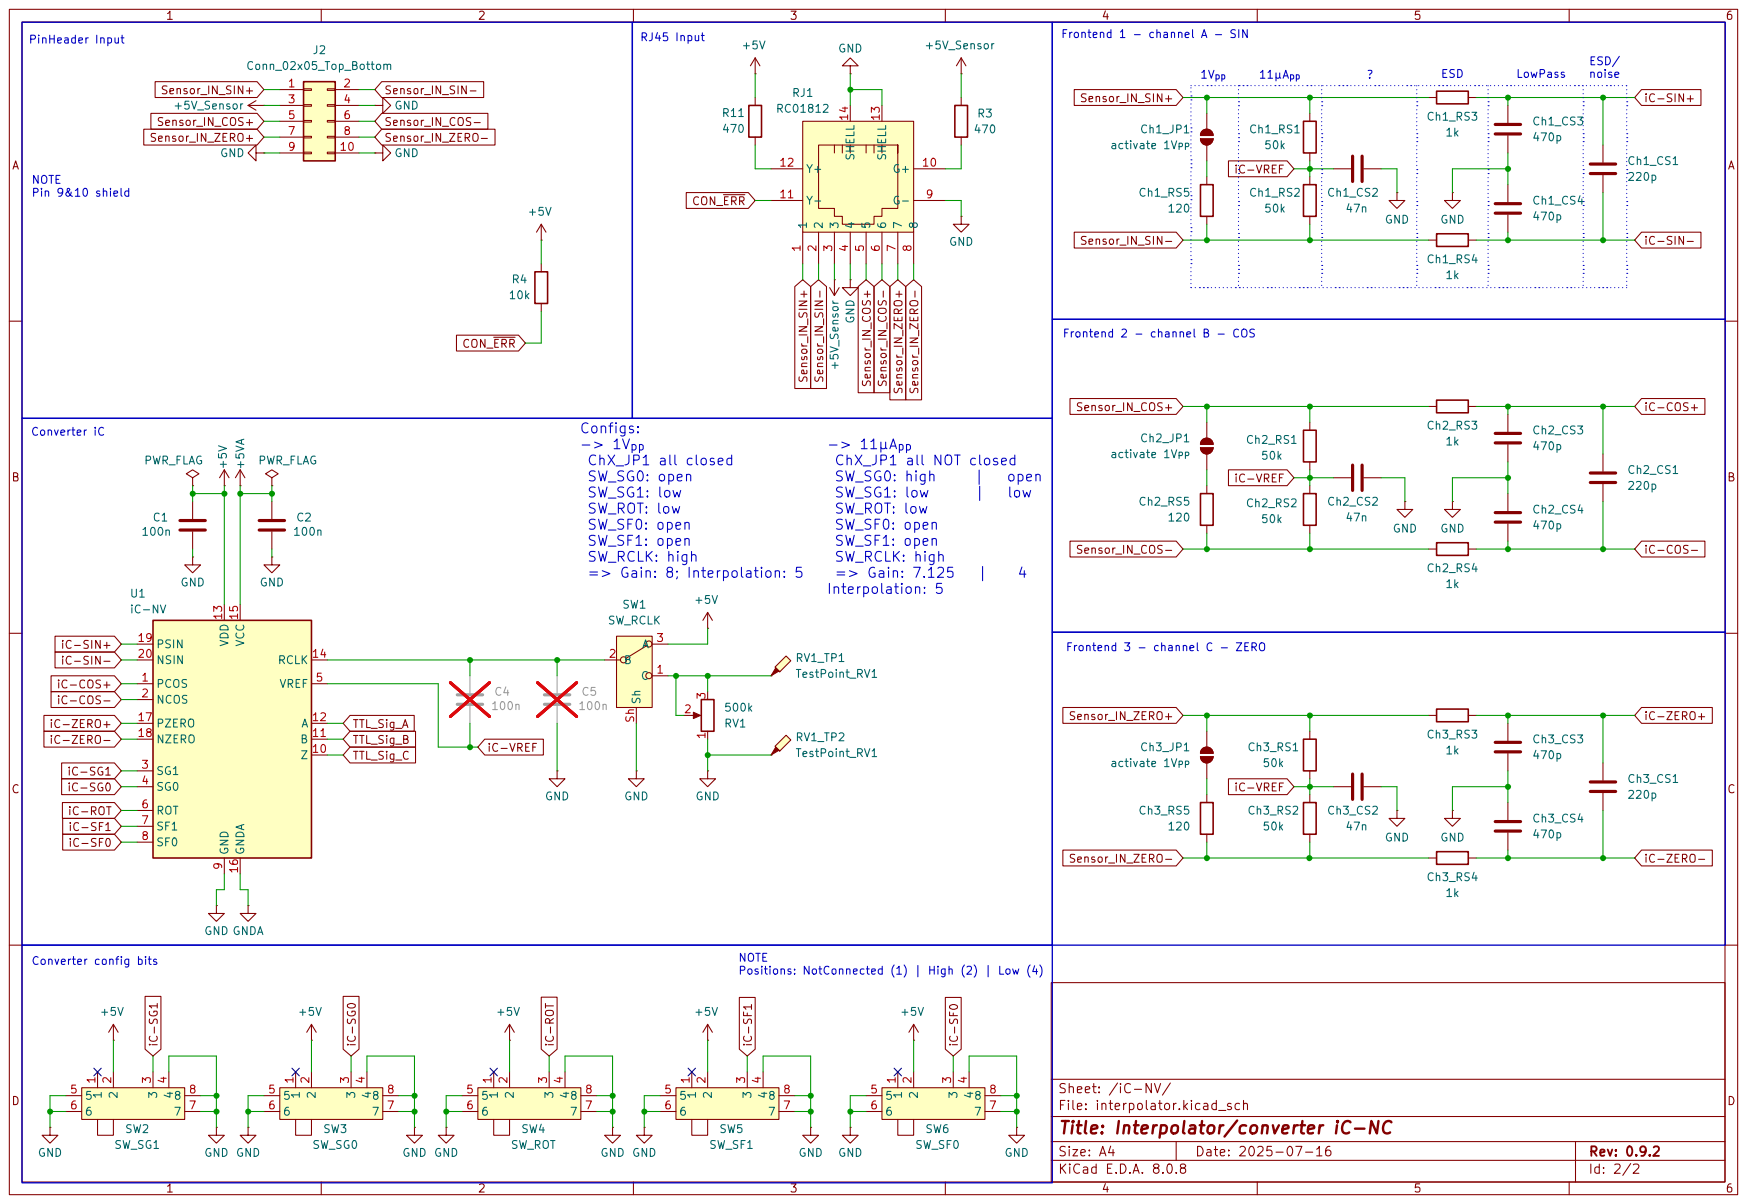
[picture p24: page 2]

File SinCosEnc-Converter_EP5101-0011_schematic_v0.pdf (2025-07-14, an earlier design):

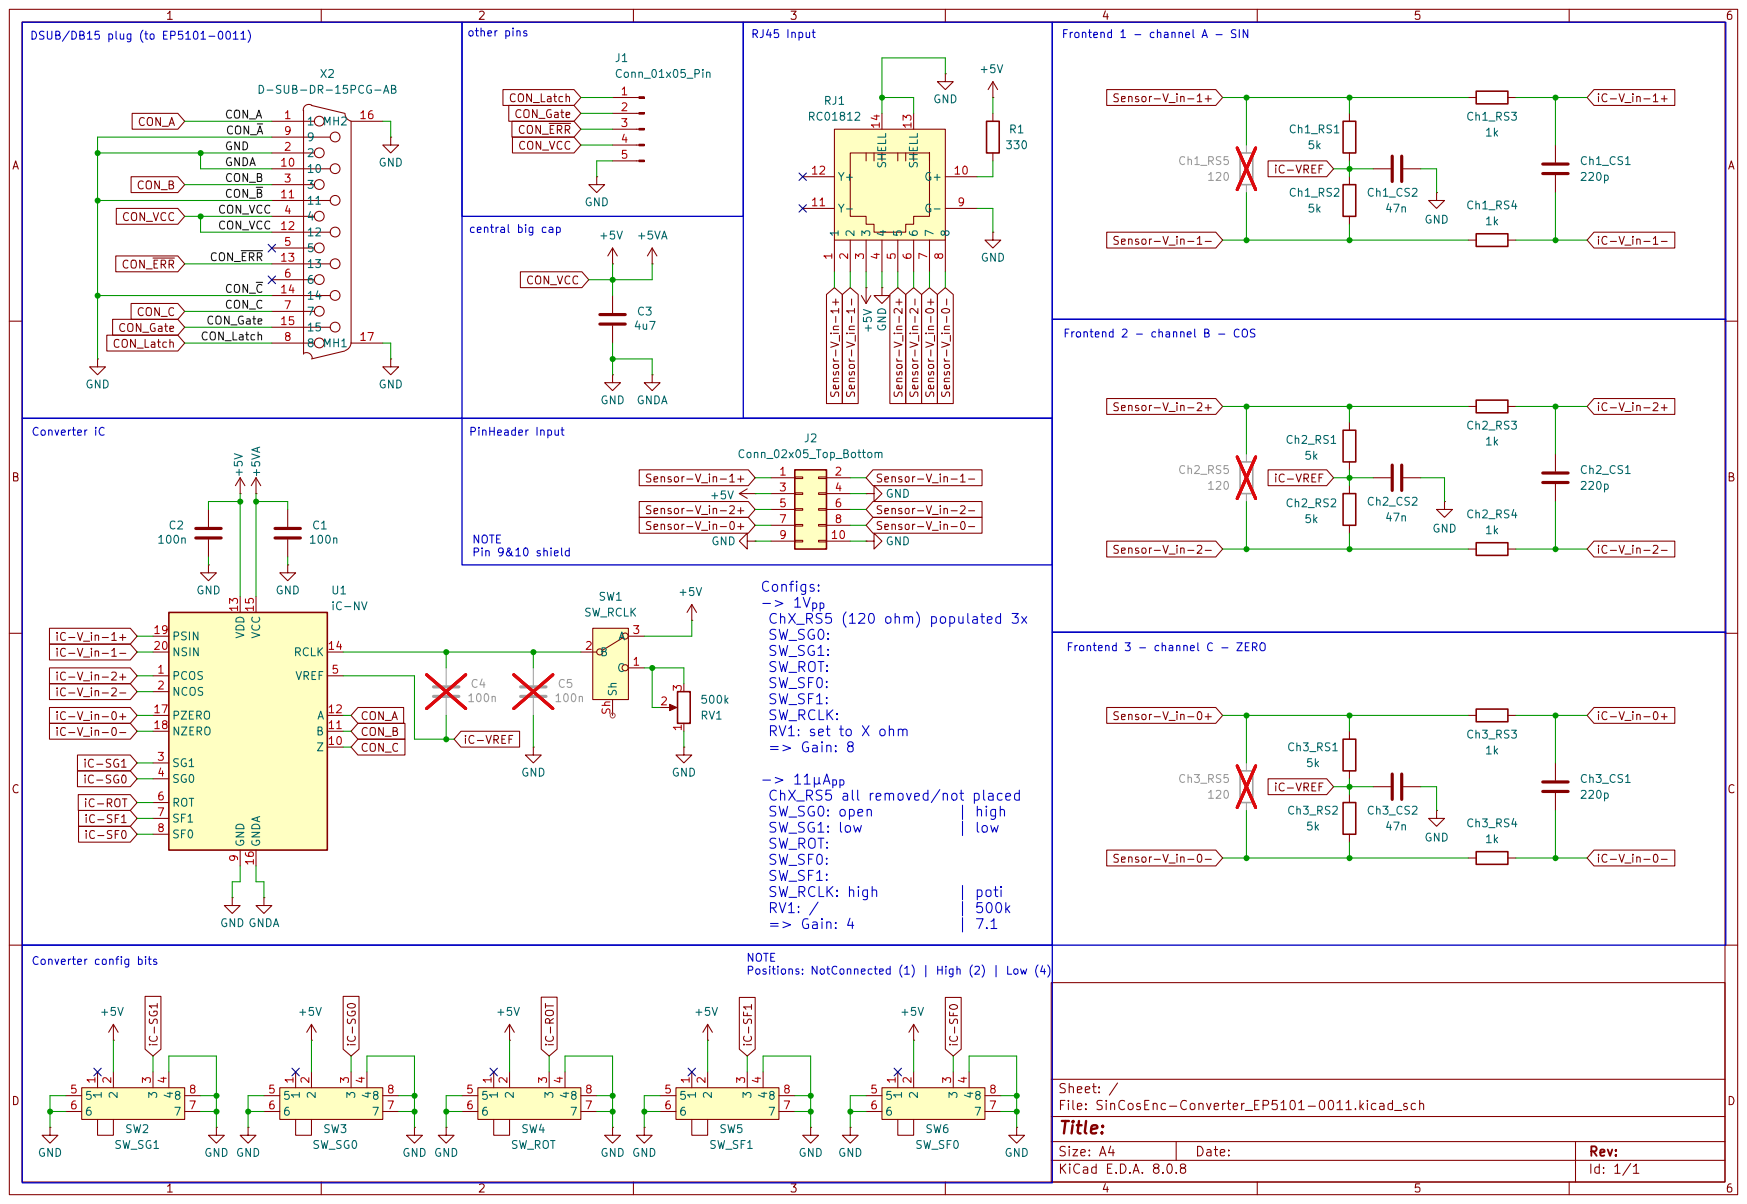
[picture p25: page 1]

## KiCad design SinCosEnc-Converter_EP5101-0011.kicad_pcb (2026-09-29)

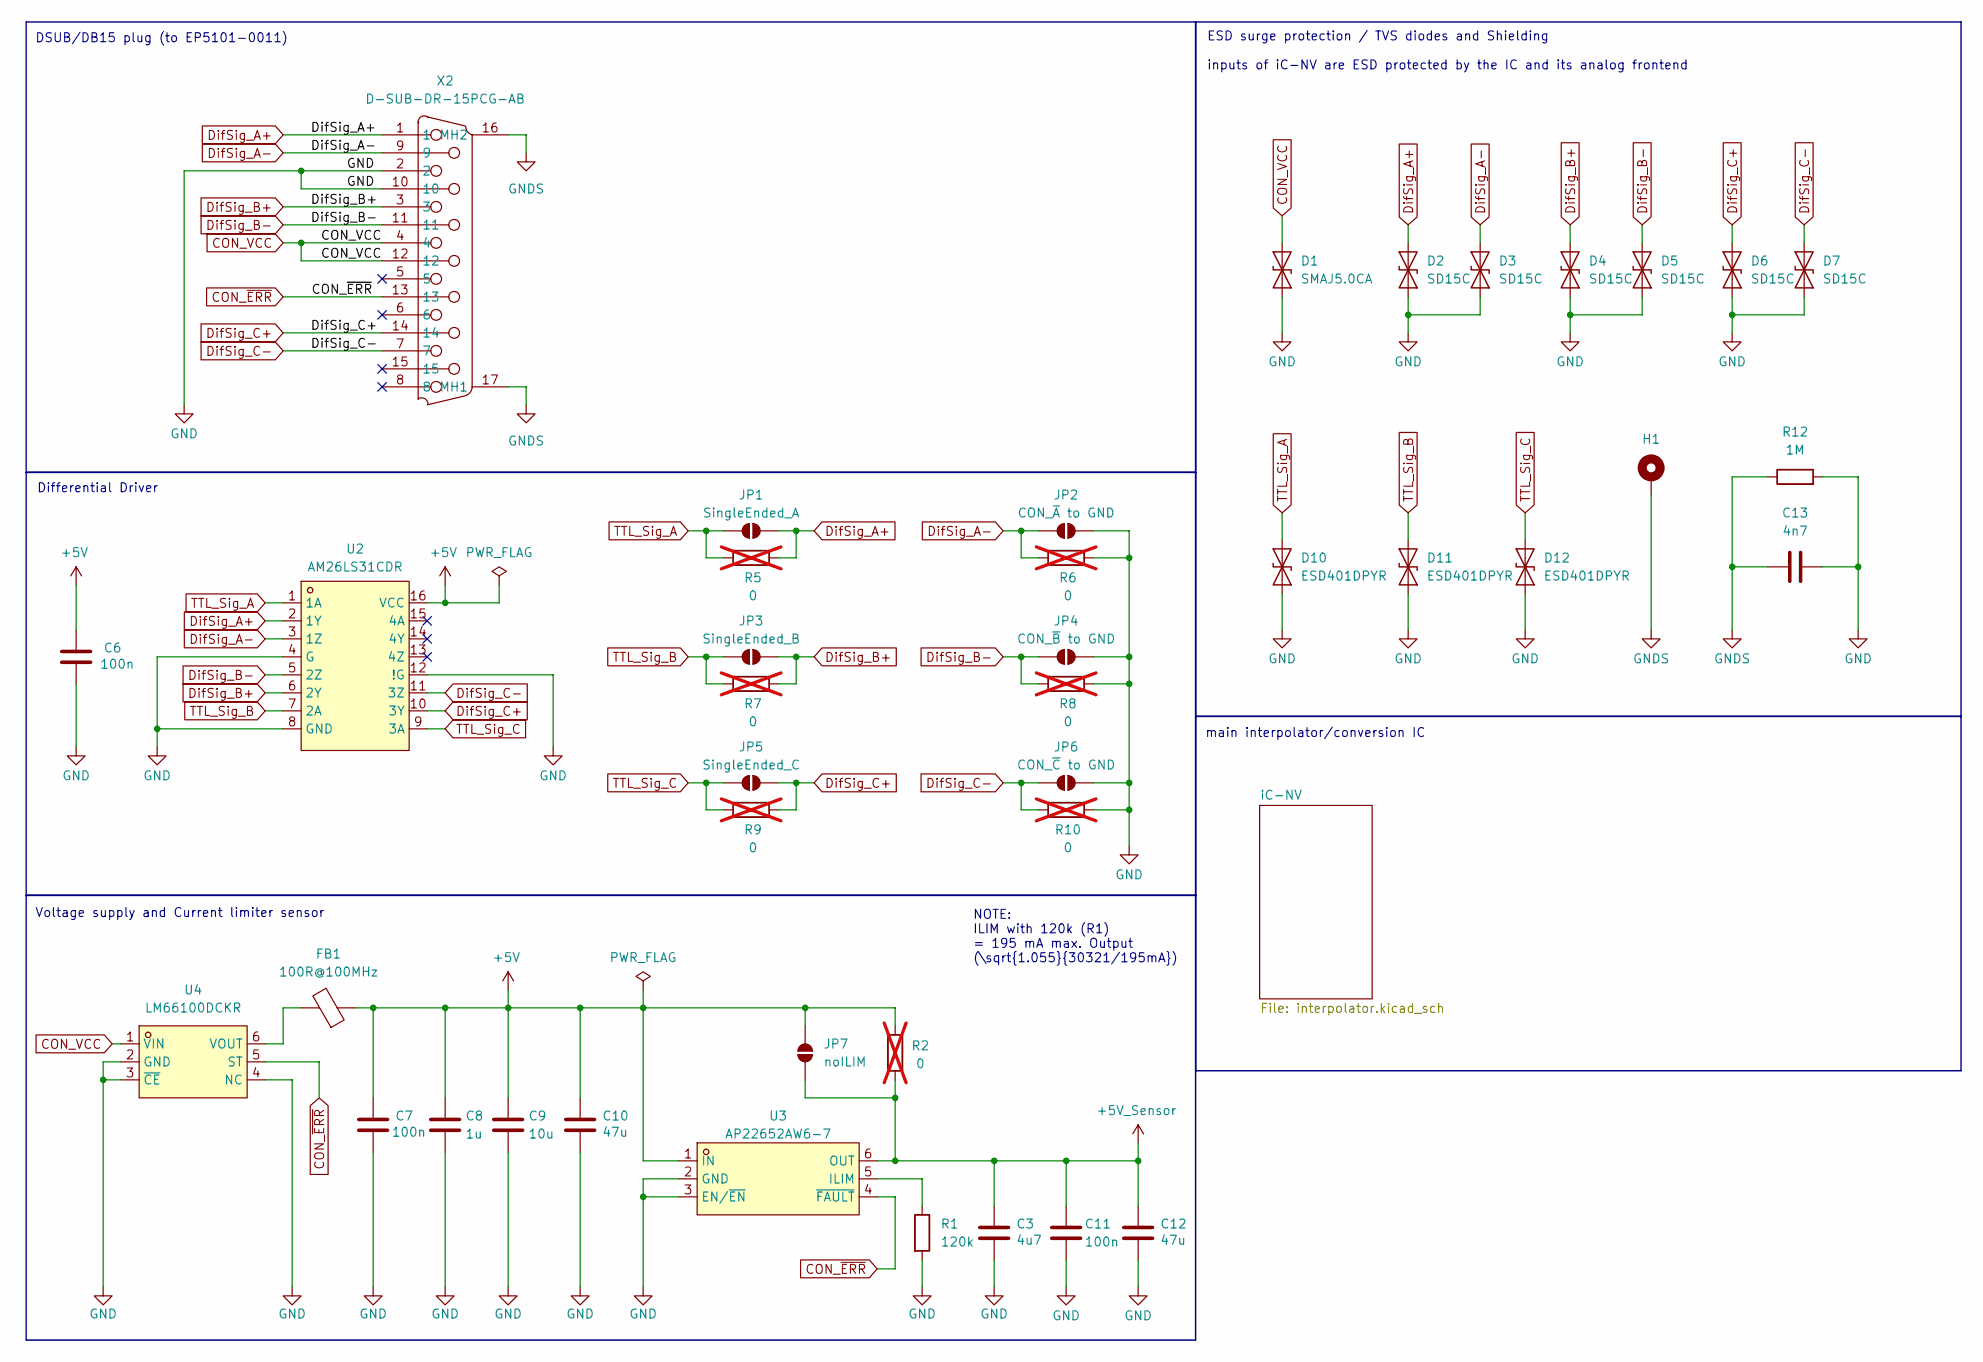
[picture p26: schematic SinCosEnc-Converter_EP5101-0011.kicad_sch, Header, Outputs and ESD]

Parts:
C3: 4u7; C_0603_1608Metric; LCSC Part C1705
C6, C7, C11: 100n; C_0603_1608Metric; LCSC Part C14663
C8: 1u; C_0603_1608Metric; LCSC Part C15849
C9: 10u; C_0603_1608Metric; LCSC Part C91606
C10, C12: 47u; C_1206_3216Metric; LCSC Part C94034
C13: 4n7; C_1808_4520Metric; LCSC Part C161101
D1: SMAJ5.0CA; D_SMA; LCSC Part C83324
D2, D3, D4, D5, D6, D7: SD15C; D_SOD-323; LCSC Part C207245
D10, D11, D12: ESD401DPYR; Texas_DPY0002A_0.6x1mm_P0.65mm; LCSC Part C1974752
FB1: 100R@100MHz; L0603; LCSC Part C107332
H1: MountingHole_Pad; MountingHole_3.2mm_M3_DIN965_Pad_TopBottom
JP1: SingleEnded_A; SolderJumper-2_P1.3mm_Open_RoundedPad1.0x1.5mm
JP2: CON_~{A} to GND; SolderJumper-2_P1.3mm_Open_RoundedPad1.0x1.5mm
JP3: SingleEnded_B; SolderJumper-2_P1.3mm_Open_RoundedPad1.0x1.5mm
JP4: CON_~{B} to GND; SolderJumper-2_P1.3mm_Open_RoundedPad1.0x1.5mm
JP5: SingleEnded_C; SolderJumper-2_P1.3mm_Open_RoundedPad1.0x1.5mm
JP6: CON_~{C} to GND; SolderJumper-2_P1.3mm_Open_RoundedPad1.0x1.5mm
JP7: noILIM; SolderJumper-2_P1.3mm_Open_RoundedPad1.0x1.5mm
R1: 120k; R_0603_1608Metric; LCSC Part C22954
R2, R5, R6, R7, R8, R9, R10: 0; R_0603_1608Metric; not fitted
R12: 1M; R_2010_5025Metric; LCSC Part C2779367
U2: AM26LS31CDR; SOIC-16_L9.9-W3.9-P1.27-LS6.0-BL; LCSC Part C6179
U3: AP22652AW6-7; SOT-23-6_L2.9-W1.6-P0.95-LS2.8-BL; LCSC Part C5329413
U4: LM66100DCKR; SC-70-6_L2.0-W1.3-P0.65-LS2.1-BL; LCSC Part C2869734
X2: D-SUB-DR-15PCG-AB; DSUB-TH_D-SUB-DR-15PCG-AB; LCSC Part C19077347

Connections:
+5V: C6.2, C7.2, C8.2, C9.2, C10.2, FB1.1, JP7.2 (B), R2.2, U2.16 (VCC), U3.1 (IN); also elsewhere on the board
+5V_Sensor: C3.2, C11.2, C12.2, JP7.1 (A), R2.1, U3.6 (OUT); also elsewhere on the board
CON_VCC: D1.2 (A2), U4.1 (VIN), X2.4, X2.12
CON_~ERR: U3.4 (~FAULT), U4.5 (ST), X2.13; also elsewhere on the board
DifSig_A+: D2.2 (A2), JP1.2 (B), R5.1, U2.2 (1Y), X2.1
DifSig_A-: D3.2 (A2), JP2.1 (A), R6.2, U2.3 (1Z), X2.9
DifSig_B+: D4.2 (A2), JP3.2 (B), R7.1, U2.6 (2Y), X2.3
DifSig_B-: D5.2 (A2), JP4.1 (A), R8.2, U2.5 (2Z), X2.11
DifSig_C+: D6.2 (A2), JP5.2 (B), R9.1, U2.10 (3Y), X2.14
DifSig_C-: D7.2 (A2), JP6.1 (A), R10.2, U2.11 (3Z), X2.7
GND: C3.1, C6.1, C7.1, C8.1, C9.1, C10.1, C11.1, C12.1, C13.2, D1.1 (A1), D2.1 (A1), D3.1 (A1), D4.1 (A1), D5.1 (A1), D6.1 (A1), D7.1 (A1), D10.1 (A1), D11.1 (A1), D12.1 (A1), JP2.2 (B), JP4.2 (B), JP6.2 (B), R1.2, R6.1, R8.1, R10.1, R12.2, U2.4 (G), U2.8 (GND), U2.12 (!G), U3.2 (GND), U3.3 (EN/~EN), U4.2 (GND), U4.3 (~CE), U4.4 (NC), X2.2, X2.10; also elsewhere on the board
GNDS: C13.1, H1.1, R12.1, X2.16 (MH2), X2.17 (MH1); also elsewhere on the board
unnamed: R1.1, U3.5 (ILIM)
unnamed: FB1.2, U4.6 (VOUT)
TTL_Sig_A: D10.2 (A2), JP1.1 (A), R5.2, U2.1 (1A); also elsewhere on the board
TTL_Sig_B: D11.2 (A2), JP3.1 (A), R7.2, U2.7 (2A); also elsewhere on the board
TTL_Sig_C: D12.2 (A2), JP5.1 (A), R9.2, U2.9 (3A); also elsewhere on the board

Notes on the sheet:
main interpolator/conversion IC
NOTE: ILIM with 120k (R1) = 195 mA max. Output (\sqrt{1.055}{30321/195mA})
ESD surge protection / TVS diodes and Shielding inputs of iC-NV are ESD protected by the IC and its analog frontend
Voltage supply and Current limiter sensor
DSUB/DB15 plug (to EP5101-0011)
Differential Driver

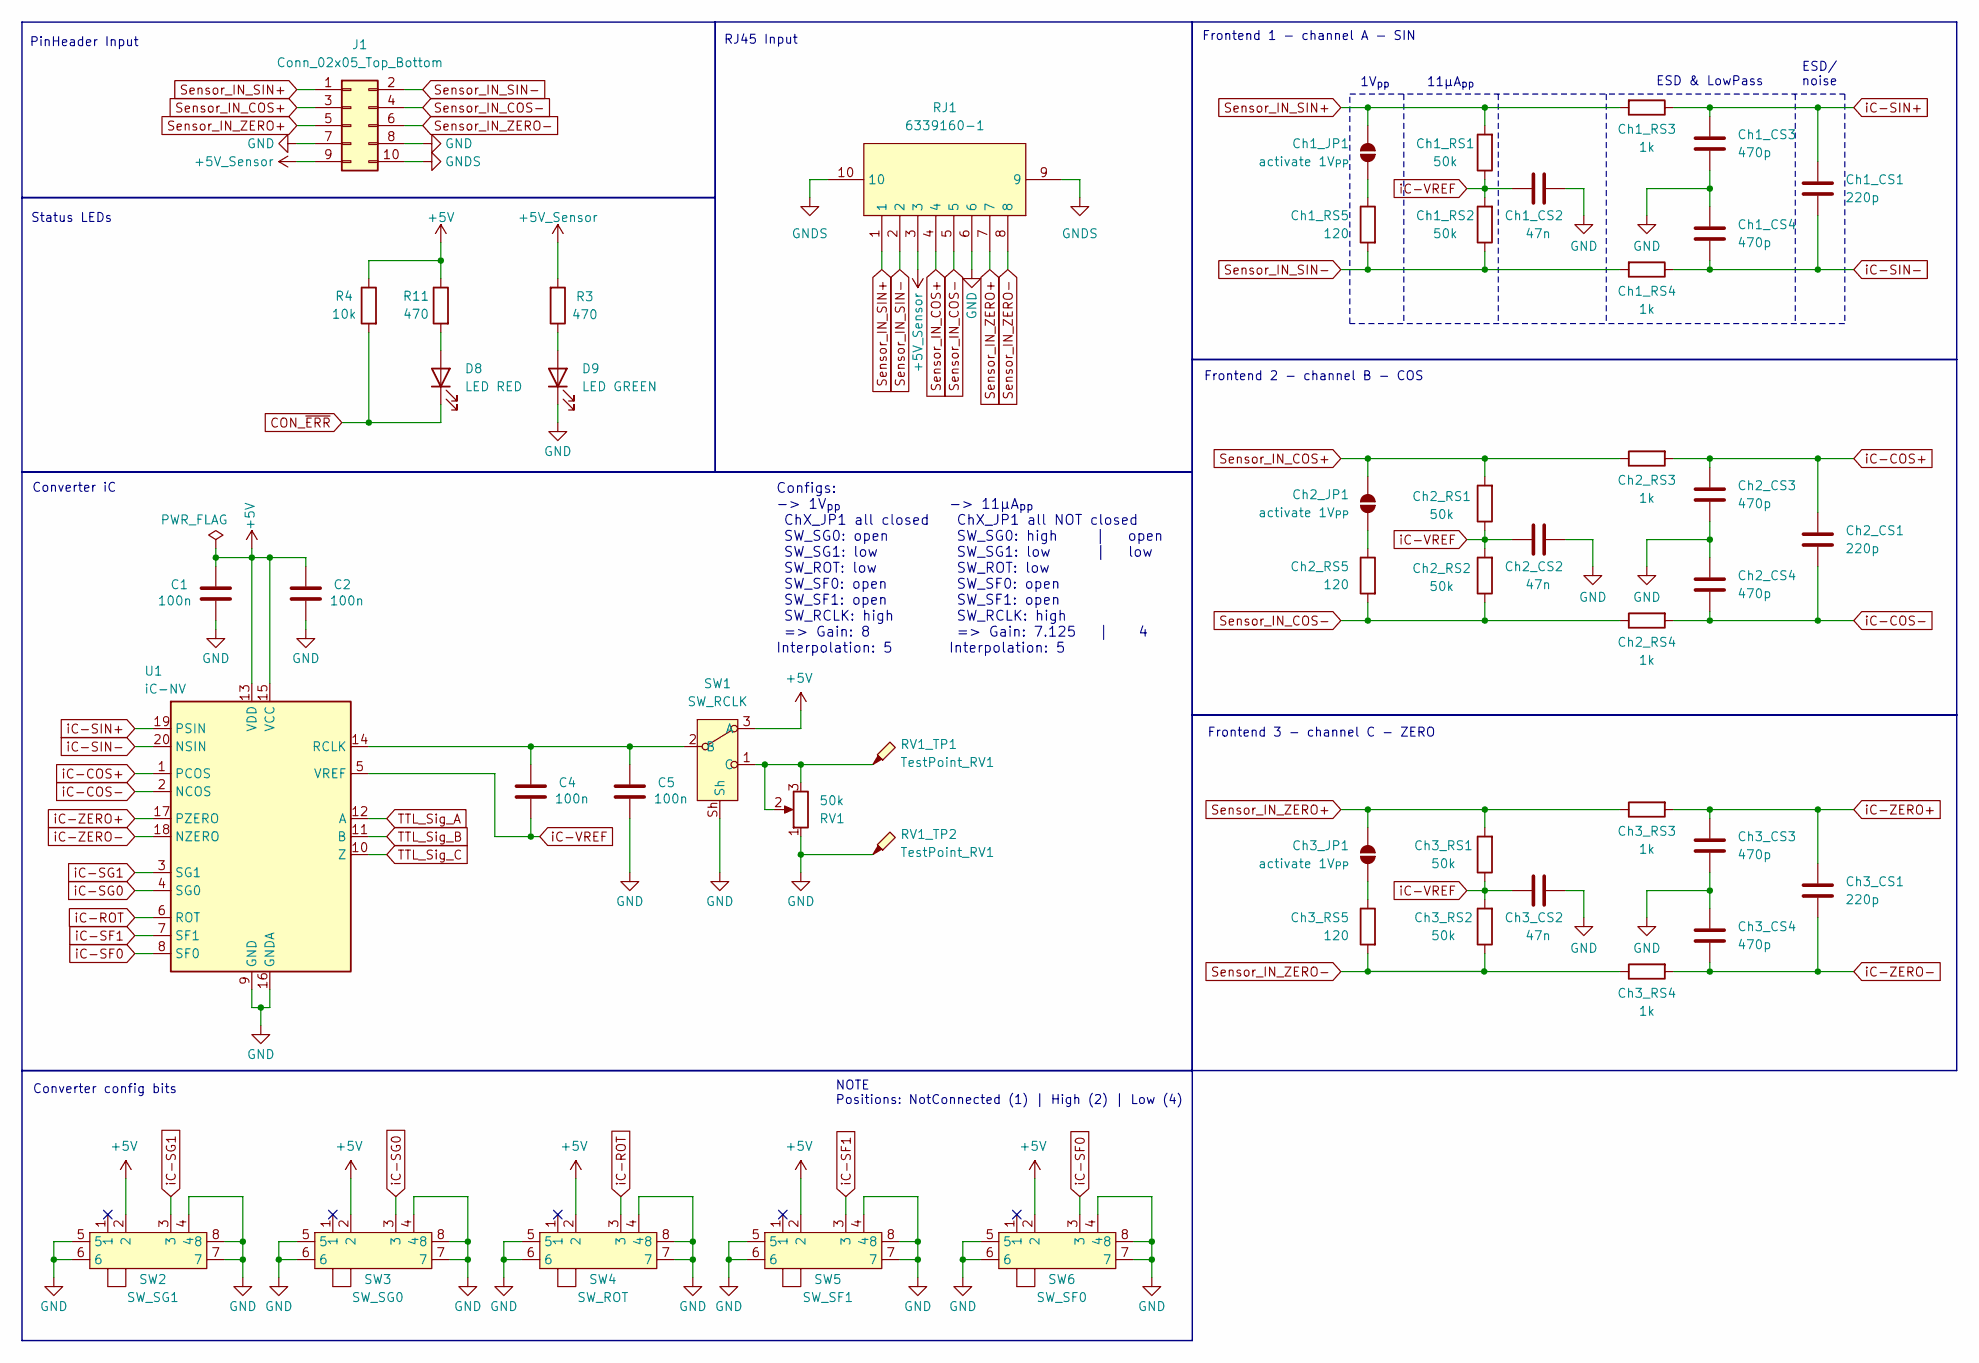
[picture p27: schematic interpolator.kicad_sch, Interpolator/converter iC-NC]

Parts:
C1, C2, C4, C5: 100n; C_0603_1608Metric; LCSC Part C14663
Ch1_CS1, Ch2_CS1, Ch3_CS1: 220p; C_0603_1608Metric; LCSC Part C107081
Ch1_CS2, Ch2_CS2, Ch3_CS2: 47n; C_0603_1608Metric; LCSC Part C1622
Ch1_CS3, Ch1_CS4, Ch2_CS3, Ch2_CS4, Ch3_CS3, Ch3_CS4: 470p; C_0603_1608Metric; LCSC Part C22396
Ch1_JP1, Ch2_JP1, Ch3_JP1: activate 1V_{PP}; SolderJumper-2_P1.3mm_Open_RoundedPad1.0x1.5mm
Ch1_RS1, Ch1_RS2, Ch2_RS1, Ch2_RS2, Ch3_RS1, Ch3_RS2: 50k; R_0603_1608Metric; LCSC Part C861451
Ch1_RS3, Ch1_RS4, Ch2_RS3, Ch2_RS4, Ch3_RS3, Ch3_RS4: 1k; R_0603_1608Metric
Ch1_RS5, Ch2_RS5, Ch3_RS5: 120; R_0603_1608Metric; LCSC Part C22787
D8: LED RED; LED_0603_1608Metric; LCSC Part C2986060
D9: LED GREEN; LED_0603_1608Metric; LCSC Part C2986059
J1: Conn_02x05_Top_Bottom; PinHeader_2x05_P2.54mm_Horizontal; LCSC Part C492433
R3, R11: 470; R_0603_1608Metric
R4: 10k; R_0603_1608Metric
RJ1: 6339160-1; RJ45-SMD_6339160-1; LCSC Part C125076
RV1: 50k; Potentiometer_Bourns_3266X_Horizontal; LCSC Part C780222
RV1_TP1: TestPoint_RV1; TestPoint_THTPad_2.0x2.0mm_Drill1.0mm
RV1_TP2: TestPoint_RV1; TestPoint_THTPad_D2.0mm_Drill1.0mm
SW1: SW_RCLK; SW-SMD_XKB_SS-3292S-L2-W; LCSC Part C2884756
SW2: SW_SG1; SW-SMD_MSK13C02-BB; LCSC Part C5149819
SW3: SW_SG0; SW-SMD_MSK13C02-BB; LCSC Part C5149819
SW4: SW_ROT; SW-SMD_MSK13C02-BB; LCSC Part C5149819
SW5: SW_SF1; SW-SMD_MSK13C02-BB; LCSC Part C5149819
SW6: SW_SF0; SW-SMD_MSK13C02-BB; LCSC Part C5149819
U1: iC-NV; TSSOP-20_4.4x6.5mm_P0.65mm

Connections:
+5V: C1.2, C2.2, R4.1, R11.1, SW1.3 (A), SW2.2, SW3.2, SW4.2, SW5.2, SW6.2, U1.13 (VDD), U1.15 (VCC); also elsewhere on the board
+5V_Sensor: J1.9, R3.2, RJ1.3; also elsewhere on the board
CON_~ERR: D8.1 (K), R4.2; also elsewhere on the board
GND: C1.1, C2.1, C5.1, Ch1_CS2.2, Ch1_CS3.2, Ch1_CS4.1, Ch2_CS2.2, Ch2_CS3.2, Ch2_CS4.1, Ch3_CS2.2, Ch3_CS3.2, Ch3_CS4.1, D9.1 (K), J1.7, J1.8, RJ1.6, RV1.1, RV1_TP2.1, SW1.Sh, SW2.4, SW2.5, SW2.6, SW2.7, SW2.8, SW3.4, SW3.5, SW3.6, SW3.7, SW3.8, SW4.4, SW4.5, SW4.6, SW4.7, SW4.8, SW5.4, SW5.5, SW5.6, SW5.7, SW5.8, SW6.4, SW6.5, SW6.6, SW6.7, SW6.8, U1.9 (GND), U1.16 (GNDA); also elsewhere on the board
GNDS: J1.10, RJ1.9, RJ1.10; also elsewhere on the board
unnamed: Ch1_JP1.1 (A), Ch1_RS5.1
unnamed: Ch2_JP1.1 (A), Ch2_RS5.1
unnamed: Ch3_JP1.1 (A), Ch3_RS5.1
unnamed: D8.2 (A), R11.2
unnamed: D9.2 (A), R3.1
unnamed: C4.2, C5.2, SW1.2 (B), U1.14 (RCLK)
unnamed: RV1.2, RV1.3, RV1_TP1.1, SW1.1 (C)
Sensor_IN_COS+: Ch2_JP1.2 (B), Ch2_RS1.2, Ch2_RS3.1, J1.3, RJ1.4
Sensor_IN_COS-: Ch2_RS2.1, Ch2_RS4.1, Ch2_RS5.2, J1.4, RJ1.5
Sensor_IN_SIN+: Ch1_JP1.2 (B), Ch1_RS1.2, Ch1_RS3.2, J1.1, RJ1.1
Sensor_IN_SIN-: Ch1_RS2.1, Ch1_RS4.2, Ch1_RS5.2, J1.2, RJ1.2
Sensor_IN_ZERO+: Ch3_JP1.2 (B), Ch3_RS1.2, Ch3_RS3.1, J1.5, RJ1.7
Sensor_IN_ZERO-: Ch3_RS2.1, Ch3_RS4.1, Ch3_RS5.2, J1.6, RJ1.8
TTL_Sig_A: U1.12 (A); also elsewhere on the board
TTL_Sig_B: U1.11 (B); also elsewhere on the board
TTL_Sig_C: U1.10 (Z); also elsewhere on the board
iC-COS+: Ch2_CS1.1, Ch2_CS3.1, Ch2_RS3.2, U1.1 (PCOS)
iC-COS-: Ch2_CS1.2, Ch2_CS4.2, Ch2_RS4.2, U1.2 (NCOS)
iC-ROT: SW4.3, U1.6 (ROT)
iC-SF0: SW6.3, U1.8 (SF0)
iC-SF1: SW5.3, U1.7 (SF1)
iC-SG0: SW3.3, U1.4 (SG0)
iC-SG1: SW2.3, U1.3 (SG1)
iC-SIN+: Ch1_CS1.1, Ch1_CS3.1, Ch1_RS3.1, U1.19 (PSIN)
iC-SIN-: Ch1_CS1.2, Ch1_CS4.2, Ch1_RS4.1, U1.20 (NSIN)
iC-VREF: C4.1, Ch1_CS2.1, Ch1_RS1.1, Ch1_RS2.2, Ch2_CS2.1, Ch2_RS1.1, Ch2_RS2.2, Ch3_CS2.1, Ch3_RS1.1, Ch3_RS2.2, U1.5 (VREF)
iC-ZERO+: Ch3_CS1.1, Ch3_CS3.1, Ch3_RS3.2, U1.17 (PZERO)
iC-ZERO-: Ch3_CS1.2, Ch3_CS4.2, Ch3_RS4.2, U1.18 (NZERO)

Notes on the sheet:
Frontend 3 - channel C - ZERO
Converter config bits
Status LEDs
Frontend 1 - channel A - SIN
Frontend 2 - channel B - COS
RJ45 Input
Converter iC
11µA_{pp}
-> 11µA_{pp} ChX_JP1 all NOT closed SW_SG0: high | open SW_SG1: low | low SW_ROT: low SW_SF0: open SW_SF1: open SW_RCLK: high => Gain: 7.125 | 4 Interpolation: 5
NOTE Positions: NotConnected (1) | High (2) | Low (4)
ESD/ noise
PinHeader Input
Configs: -> 1V_{pp} ChX_JP1 all closed SW_SG0: open SW_SG1: low SW_ROT: low SW_SF0: open SW_SF1: open SW_RCLK: high => Gain: 8 Interpolation: 5
1V_{pp}
ESD & LowPass

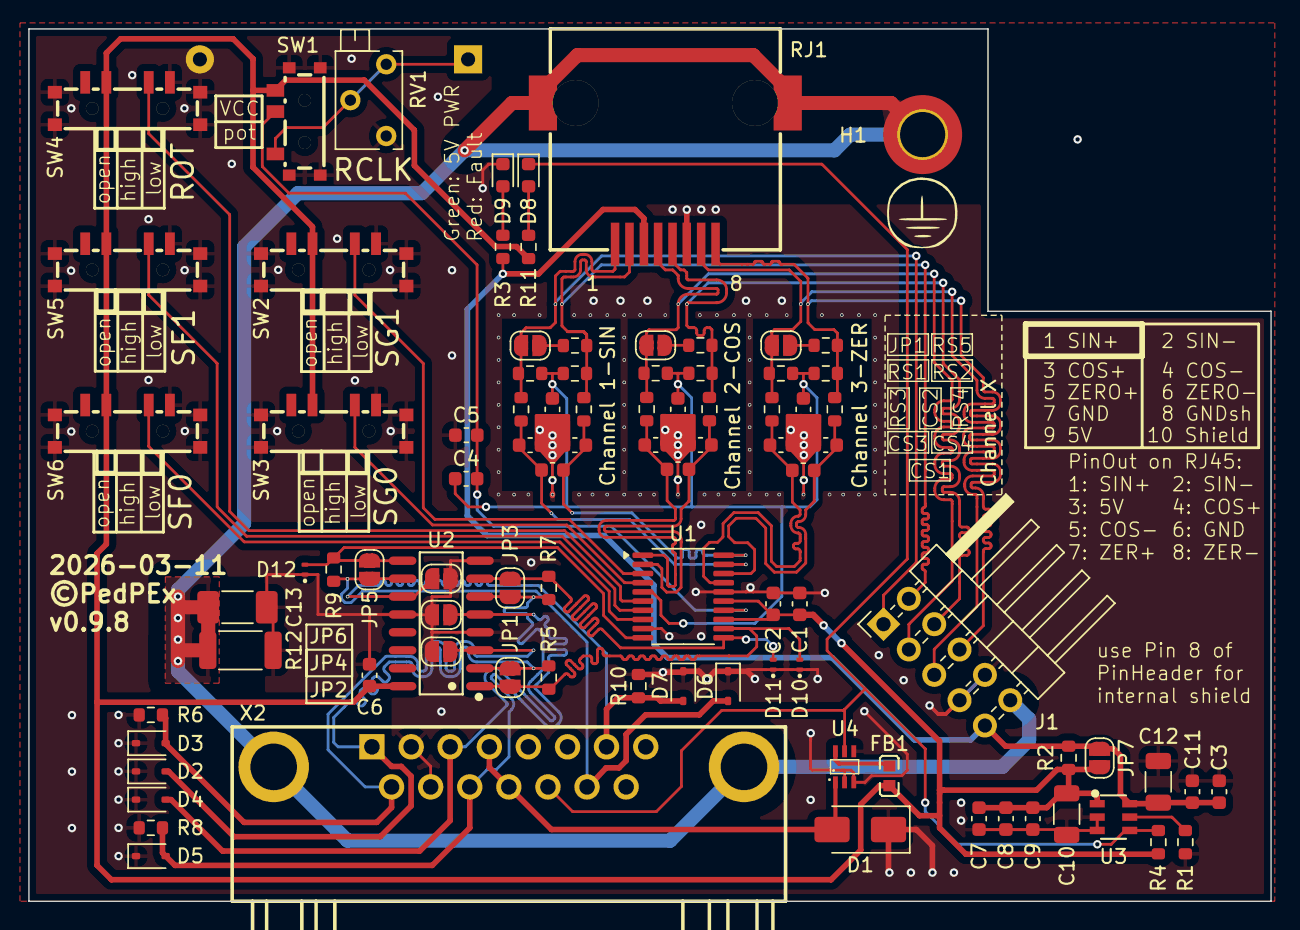
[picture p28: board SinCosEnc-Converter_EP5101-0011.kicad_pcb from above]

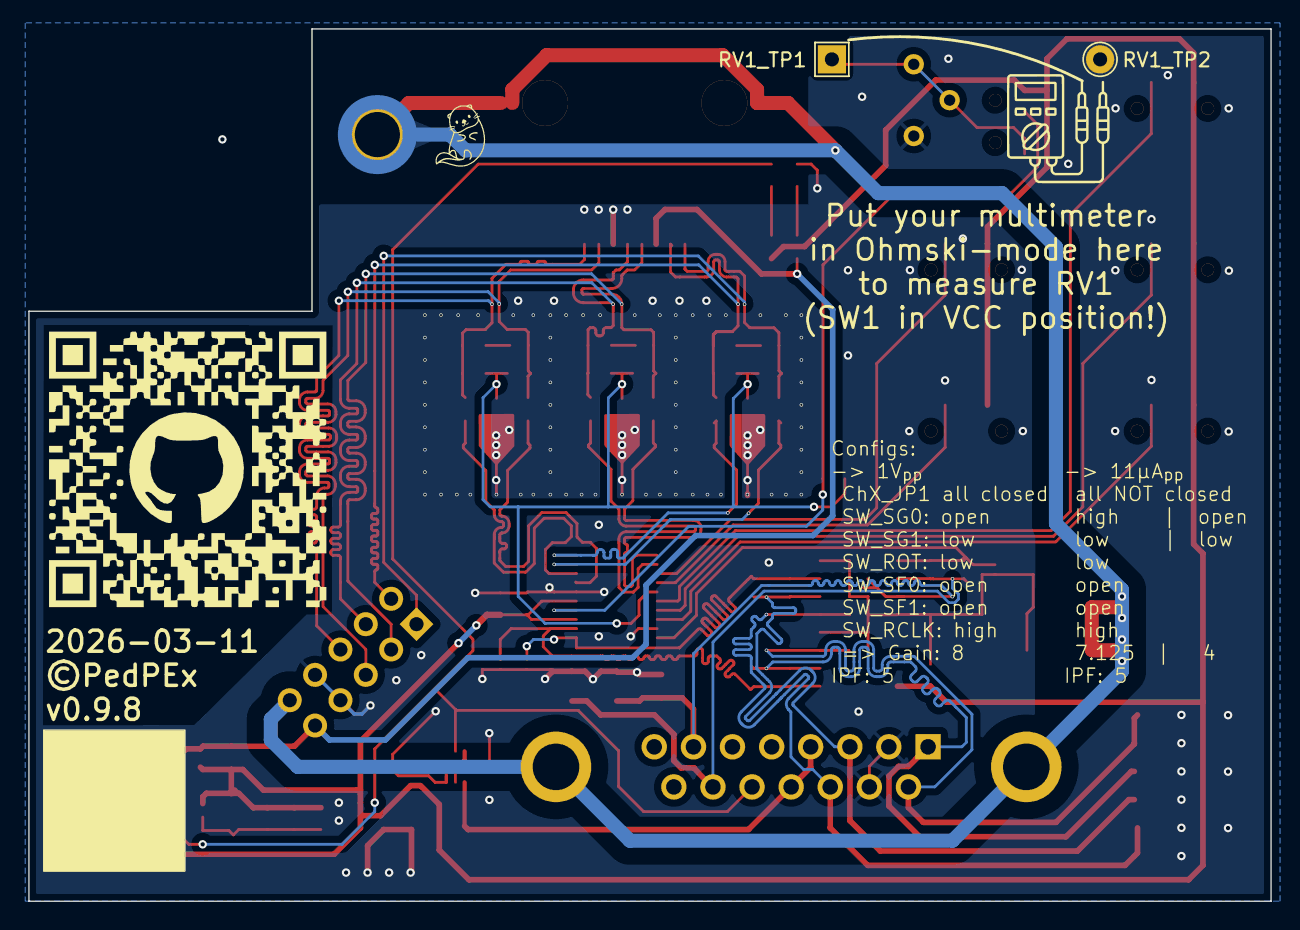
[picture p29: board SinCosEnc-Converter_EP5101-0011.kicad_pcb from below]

Board: 2 copper layers, 88.0 x 61.8 mm, 92 parts (2 on the bottom side), 42 nets.

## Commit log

2025-05-18 schematic finished ~90%, layout: just outline done added mounting concept pictures
    [SinCosEnc-Converter_EP5101-0011.kicad_pcb, SinCosEnc-Converter_EP5101-0011.kicad_sch]
2025-05-27 minor progress
    [EP5101-0011_DinRail_CON-downside_v3.3mf, EP5101-0011_DinRail_CON-downside_v4.3mf, SinCosEnc-Converter_EP5101-0011.kicad_pcb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]
2025-07-14 finished schematics for v0.9.0, PCB ToDo
    [SinCosEnc-Converter_EP5101-0011.kicad_sch, interpolator.kicad_sch]
2025-07-15 further ESD protection, PCB layout started
    [SinCosEnc-Converter_EP5101-0011.kicad_pcb, SinCosEnc-Converter_EP5101-0011.kicad_sch, interpolator.kicad_sch]
2025-07-16 v0.9.2 finished, board routed
    [SinCosEnc-Converter_EP5101-0011.kicad_pcb, SinCosEnc-Converter_EP5101-0011.kicad_sch, interpolator.kicad_sch]
2025-07-17 first theoretical working PCB finished (v0.9.3)
    [SinCosEnc-Converter_EP5101-0011.kicad_pcb, SinCosEnc-Converter_EP5101-0011.kicad_sch, SinCosEnc-Converter_EP5101-0011.step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]
2025-07-18 cleaned up board layout -> v0.9.5 from v0.9.5 to v0.9.5 just minor optical improvements were done
    [SinCosEnc-Converter_EP5101-0011.kicad_pcb, SinCosEnc-Converter_EP5101-0011.kicad_sch, SinCosEnc-Converter_EP5101-0011_v094.step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]
2025-07-27 version 0.9.6 finished
    [SinCosEnc-Converter_EP5101-0011.kicad_pcb, SinCosEnc-Converter_EP5101-0011.kicad_sch, SinCosEnc-Converter_EP5101-0011_v096.step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]
2026-09-29 Last unfinished project state -> ARCHIVED
    PCB version v0.9.6 was fully working and successfully tested. Version v0.9.8 was never produced nor tested.
    This board is provided as is - unfinished and untested. Productive use is explicitly not recommended! Further rework is required. No support is offered for it. The project will be left as is.
    [SinCosEnc-Converter_EP5101-0011.kicad_pcb, SinCosEnc-Converter_EP5101-0011.kicad_sch, interpolator.kicad_sch]

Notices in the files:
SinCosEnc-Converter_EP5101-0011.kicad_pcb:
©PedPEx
